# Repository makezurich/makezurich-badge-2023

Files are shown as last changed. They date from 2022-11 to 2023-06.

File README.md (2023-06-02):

## #MakeZurich 2023 Badge

## Pinout
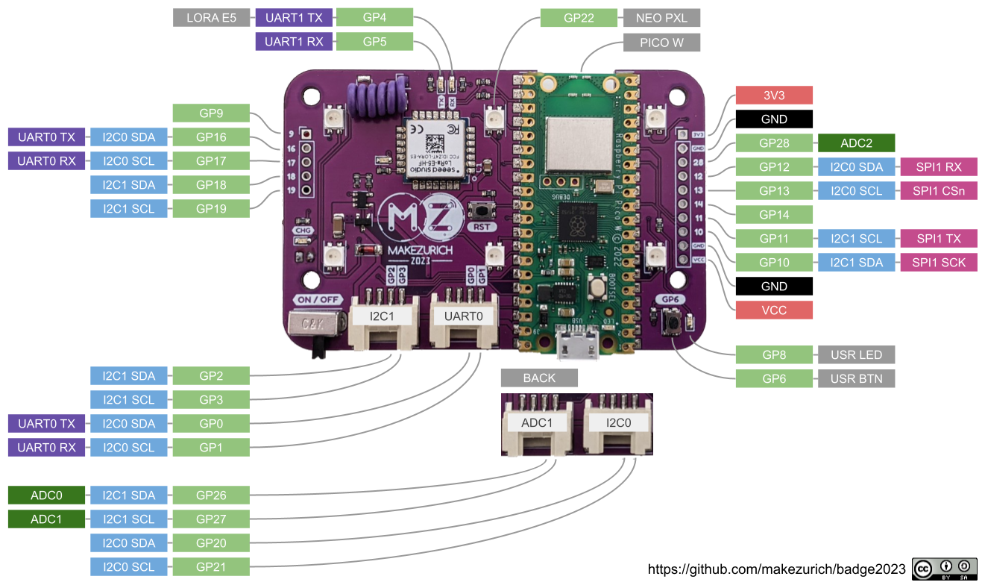
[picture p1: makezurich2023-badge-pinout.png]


## PSU
* Adafruit Feather LiPo circuit

## IO
* LoRa E5
* Shitty Addon
* Cover connectors 
* Grove connectors

## Resources

### CircuitPython
https://github.com/makezurich/badge2023-circuitpython

https://github.com/todbot/circuitpython-tricks

https://www.circuitpython.org

### LoRa E5
https://wiki.seeedstudio.com/Grove_LoRa_E5_New_Version/

https://www.hackster.io/sidikalamini/grove-lora-e5-p2p-communication-using-circuitpython-f970e6

https://files.seeedstudio.com/products/317990687/res/LoRa-E5%20AT%20Command%20Specification_V1.0%20.pdf

#### Version
| title | date | author | id | mainfont | toc | toc-depth |
| --- | --- | --- | --- | --- | --- | --- |
|"Badge"|2022-09-20|Tillo|20220920183855|Cochin|true|2|
|"Badge"|2023-04-24|Fede|?|Cochin|true|2|
|"Badge"|2023-05-12|Fede|?|Cochin|true|2|

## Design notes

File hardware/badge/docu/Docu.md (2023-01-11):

---
title: "Badge"
date: 2022-09-20
author: Tillo
id: 20220920183855
mainfont: Cochin
toc: true
toc-depth: 2
---

## Badge 20.9.

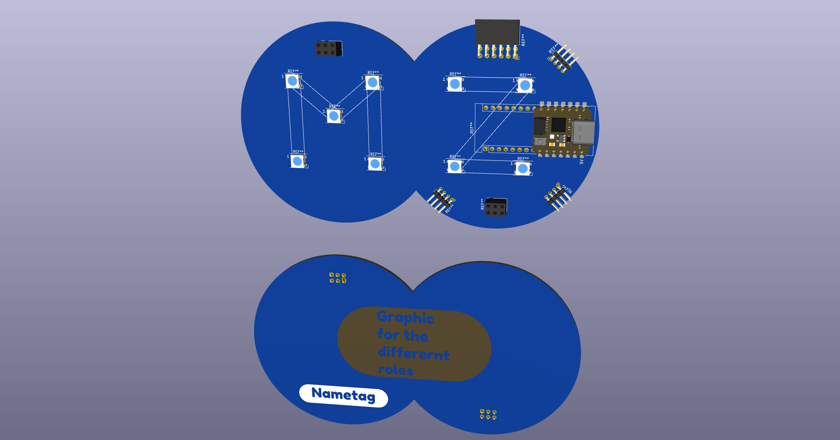
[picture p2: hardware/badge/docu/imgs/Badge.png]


## MCU
* Raspi Pico W

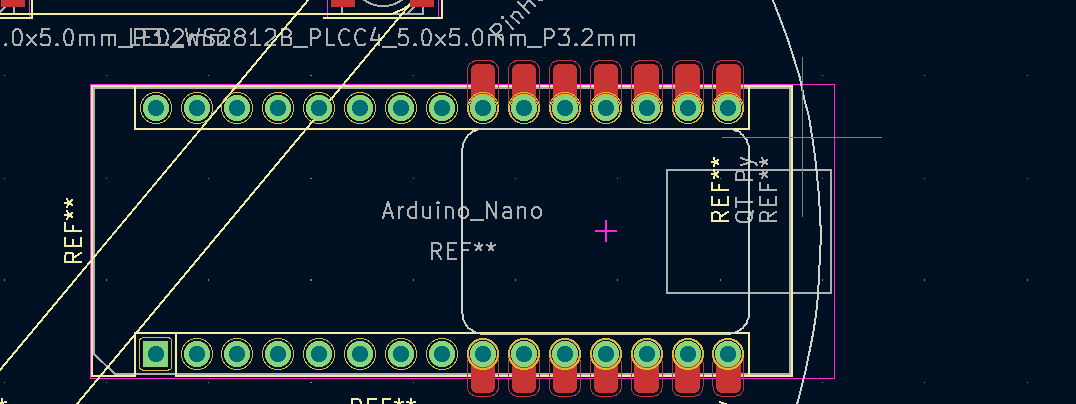
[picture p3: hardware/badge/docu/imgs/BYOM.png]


## Design 
* Sandwich
* LEDs shine trough the board
* Different graphics for the different roles 
* Touch button on the top 
* Resistors allow the badge to detect which role is plugged in

## PSU
* Same battery as last year
* Maybe ask the participants to bring their battery

## IO
* Shitty Addon
* Grove

## Prototyping area
* It was so nice let's do it twice

##  Open questions
* Batteries ?
* Shape ?
* Artwork ?
* Sponsors ? 
* µC

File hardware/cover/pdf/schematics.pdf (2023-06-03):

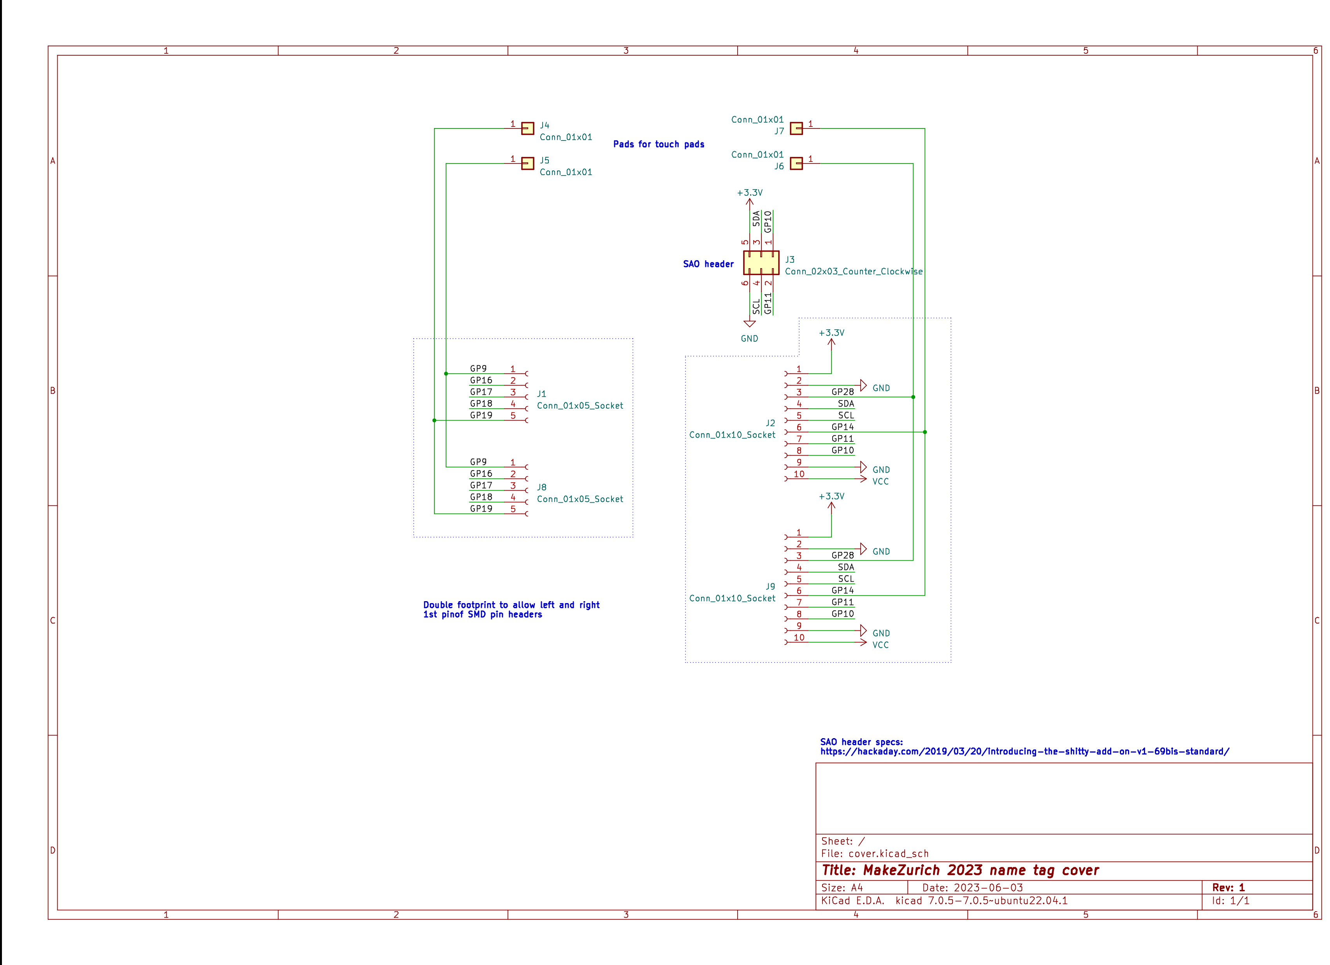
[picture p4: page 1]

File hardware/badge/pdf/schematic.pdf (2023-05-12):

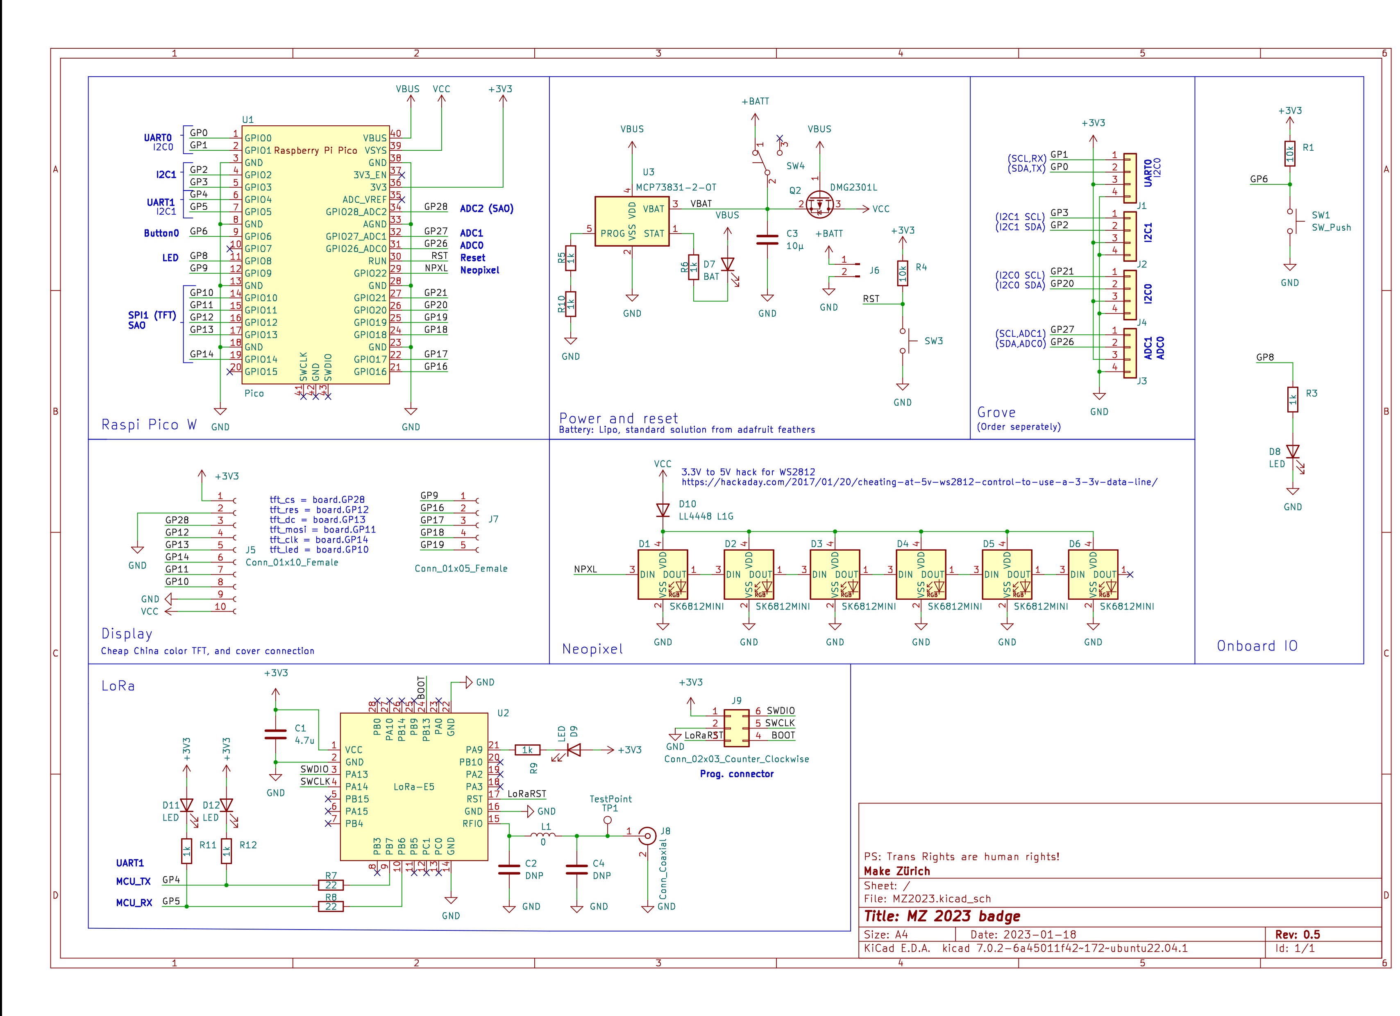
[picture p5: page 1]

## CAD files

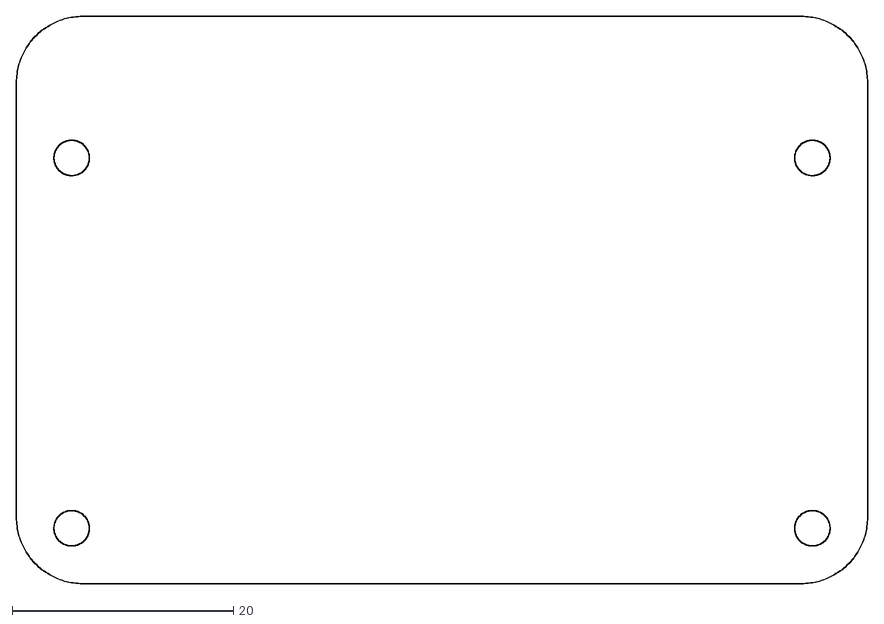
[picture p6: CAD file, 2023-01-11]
hardware/badge/docu/Badge_v20221102.dxf
77.0 x 51.3

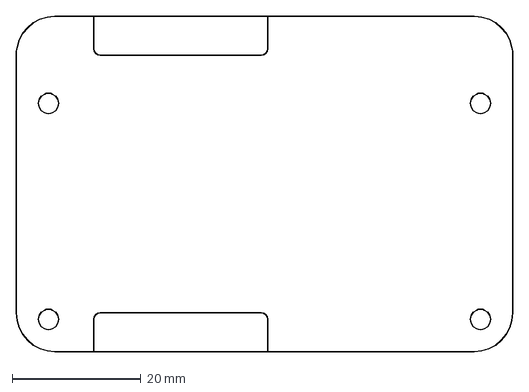
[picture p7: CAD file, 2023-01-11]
hardware/badge/docu/outlines_new.dxf
77.0 x 52.0 mm

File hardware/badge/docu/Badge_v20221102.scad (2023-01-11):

// CC BY-SA 4.0, MakeZurich.ch

$fn = 180;

// breadboard size
bbd_w = 81;
bbd_h = 51;

// AP9 box size
box_w = 77;
box_h = 77;
holes_w = 67;
holes_h = 33.5;
holes_r = 1.6;

// pico size
mcu_w = 21;
mcu_h = 51.3;
mcu_z = 3.9;

// badge size
// like breadboard
// but still fits in box
bdg_w = min(box_w, bbd_w);
bdg_h = max(min(box_h, bbd_h), mcu_h);

module base() {
  hull() {
    translate([6, 6]) {
      translate([0, 0]) {
        cylinder(1, 6, 6);
      }
      translate([bdg_w - 2 * 6, 0]) {
        cylinder(1, 6, 6);
      }
      translate([bdg_w - 2 * 6, bdg_h - 2 * 6]) {
        cylinder(1, 6, 6);
      }
      translate([0, bdg_h - 2 * 6]) {
        cylinder(1, 6, 6);
      }
    }
  }
}

module base_w_holes(){
    difference(){
        base();
        #translate([5,5,0]){
            cylinder(2,r=holes_r,center=true);
        };
        #translate([5+holes_w,5,0]){
            cylinder(2,r=holes_r,center=true);
        };        
        #translate([5,5+holes_h,0]){
            cylinder(2,r=holes_r,center=true);
        };        
        #translate([5+holes_w,5+holes_h,0]){
            cylinder(2,r=holes_r,center=true);
        };
    }
}

// board
//base_w_holes();

// translate([box_w - mcu_w - 10, 0, 1]) {
//  cube([mcu_w, mcu_h, mcu_z]);
//}

// cover
//translate([0, 0, 10]) base();

// dxf or svg export
//

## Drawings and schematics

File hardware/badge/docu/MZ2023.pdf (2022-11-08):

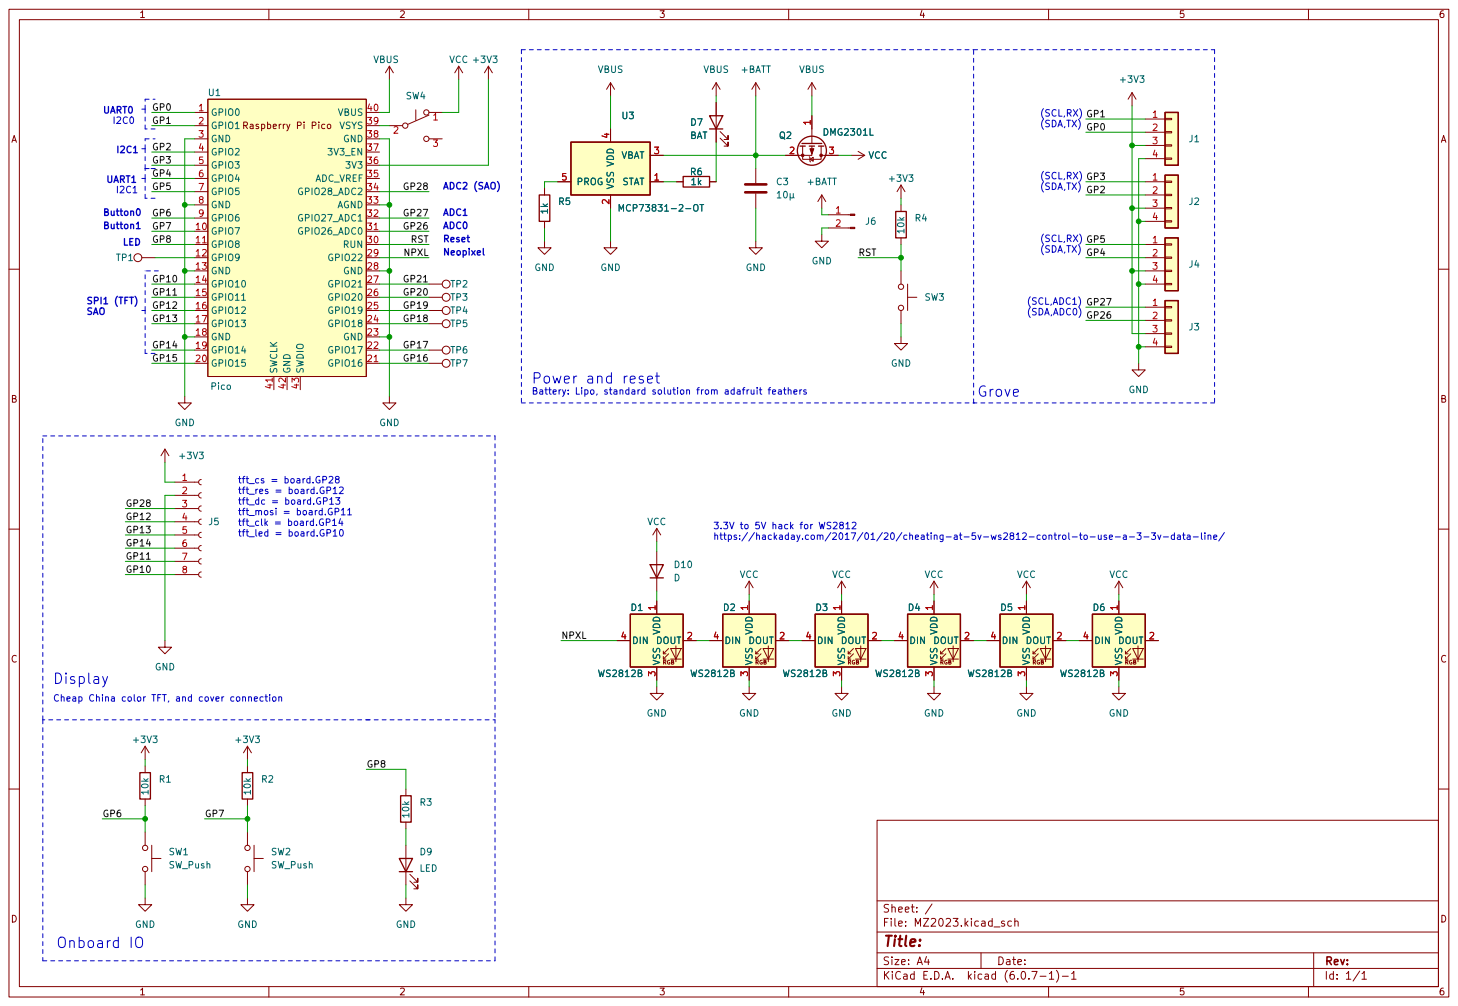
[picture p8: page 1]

I2C1 UART1 Cheap China color TFT, and cover connection

4 PROG 5 U3MCP73831-2-OT VBUS VBUS +BATT VBUS GP7 GP11 GP13 GP8 GP14 GP6

https://hackaday.com/2017/01/20/cheating-at-5v-ws2812-control-to-use-a-3-3v-data-line/ ADC1 ADC2 (SAO)

Power and reset
Battery: Lipo, standard solution from adafruit feathers

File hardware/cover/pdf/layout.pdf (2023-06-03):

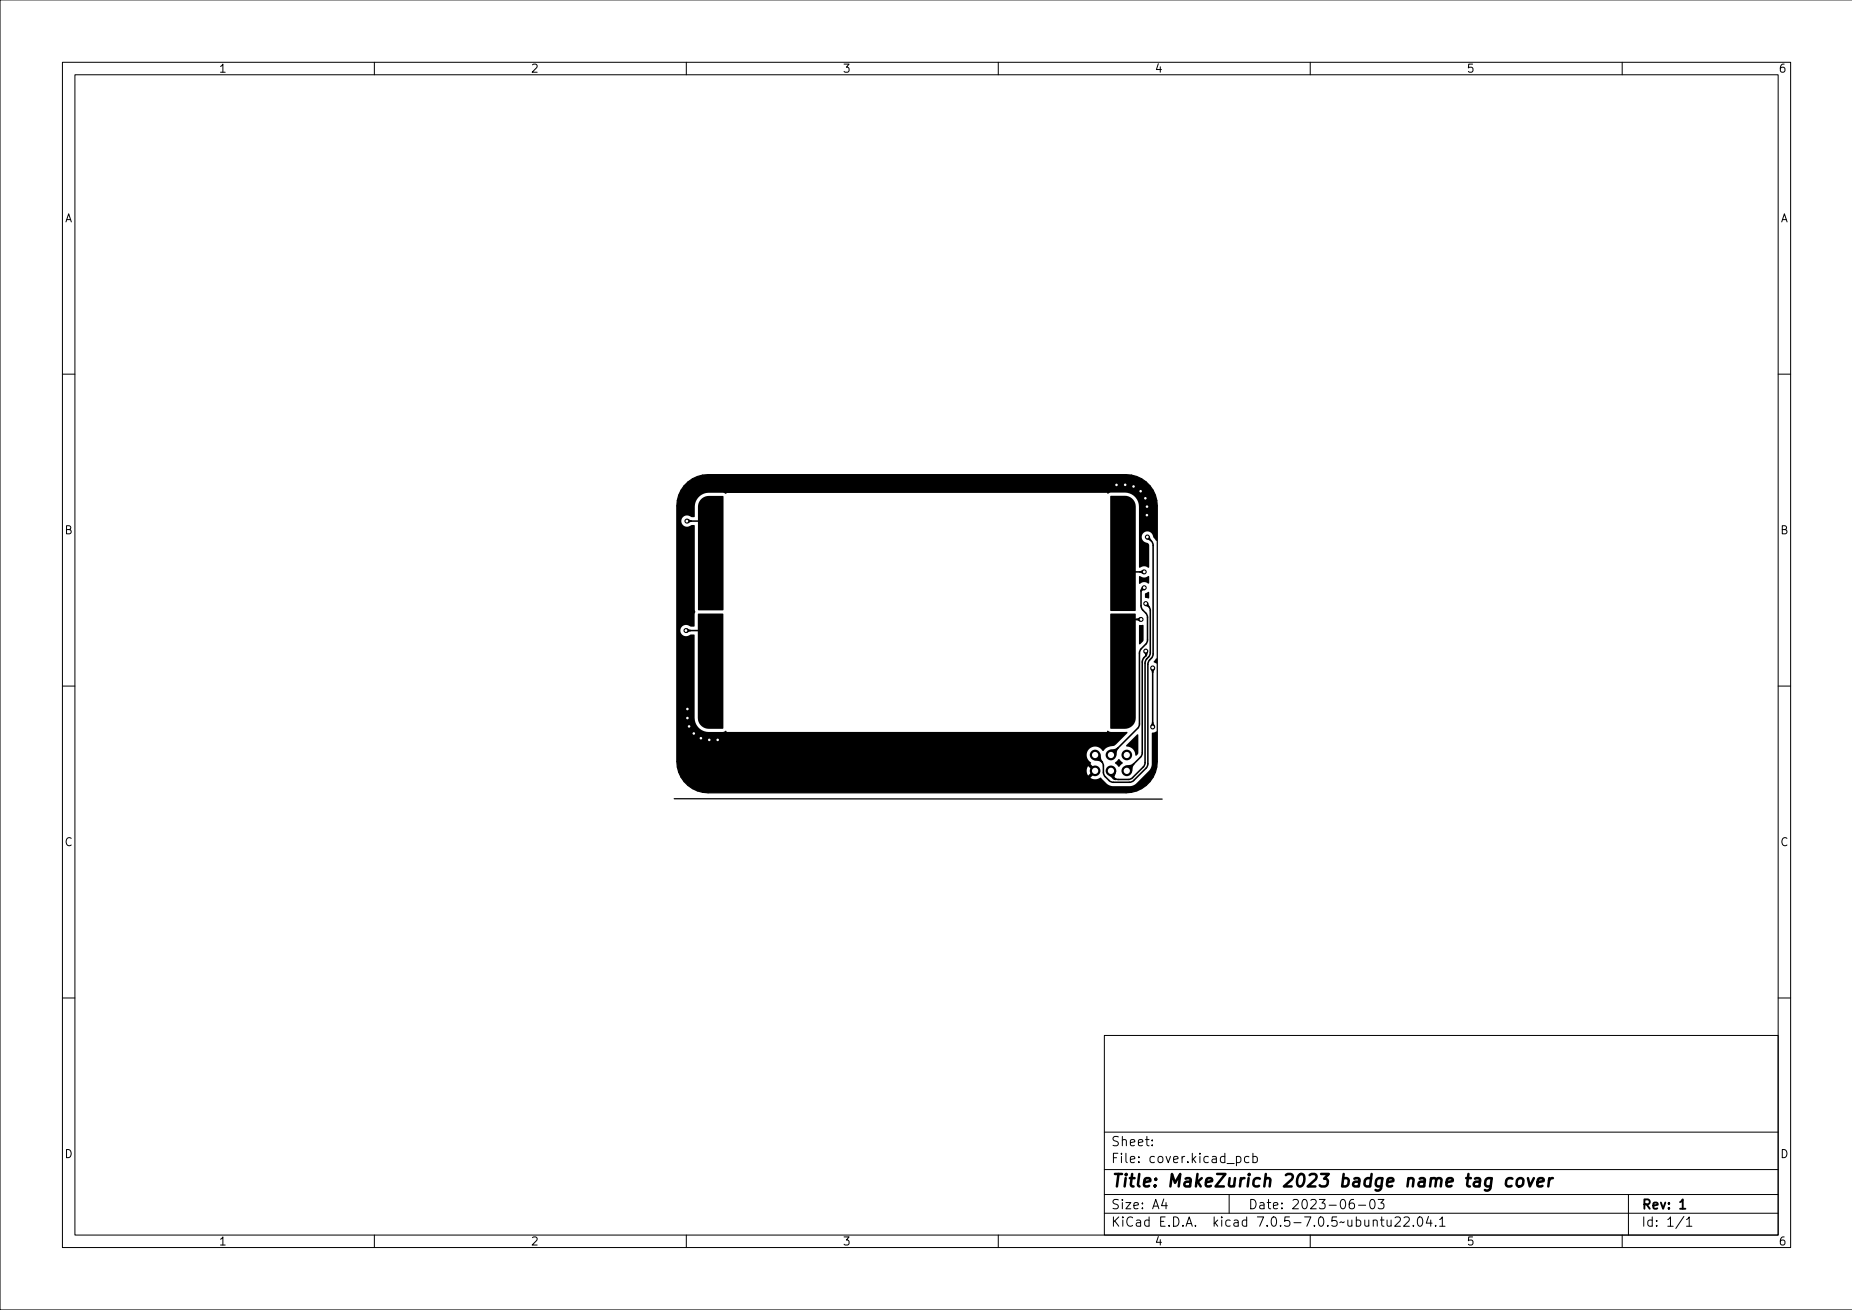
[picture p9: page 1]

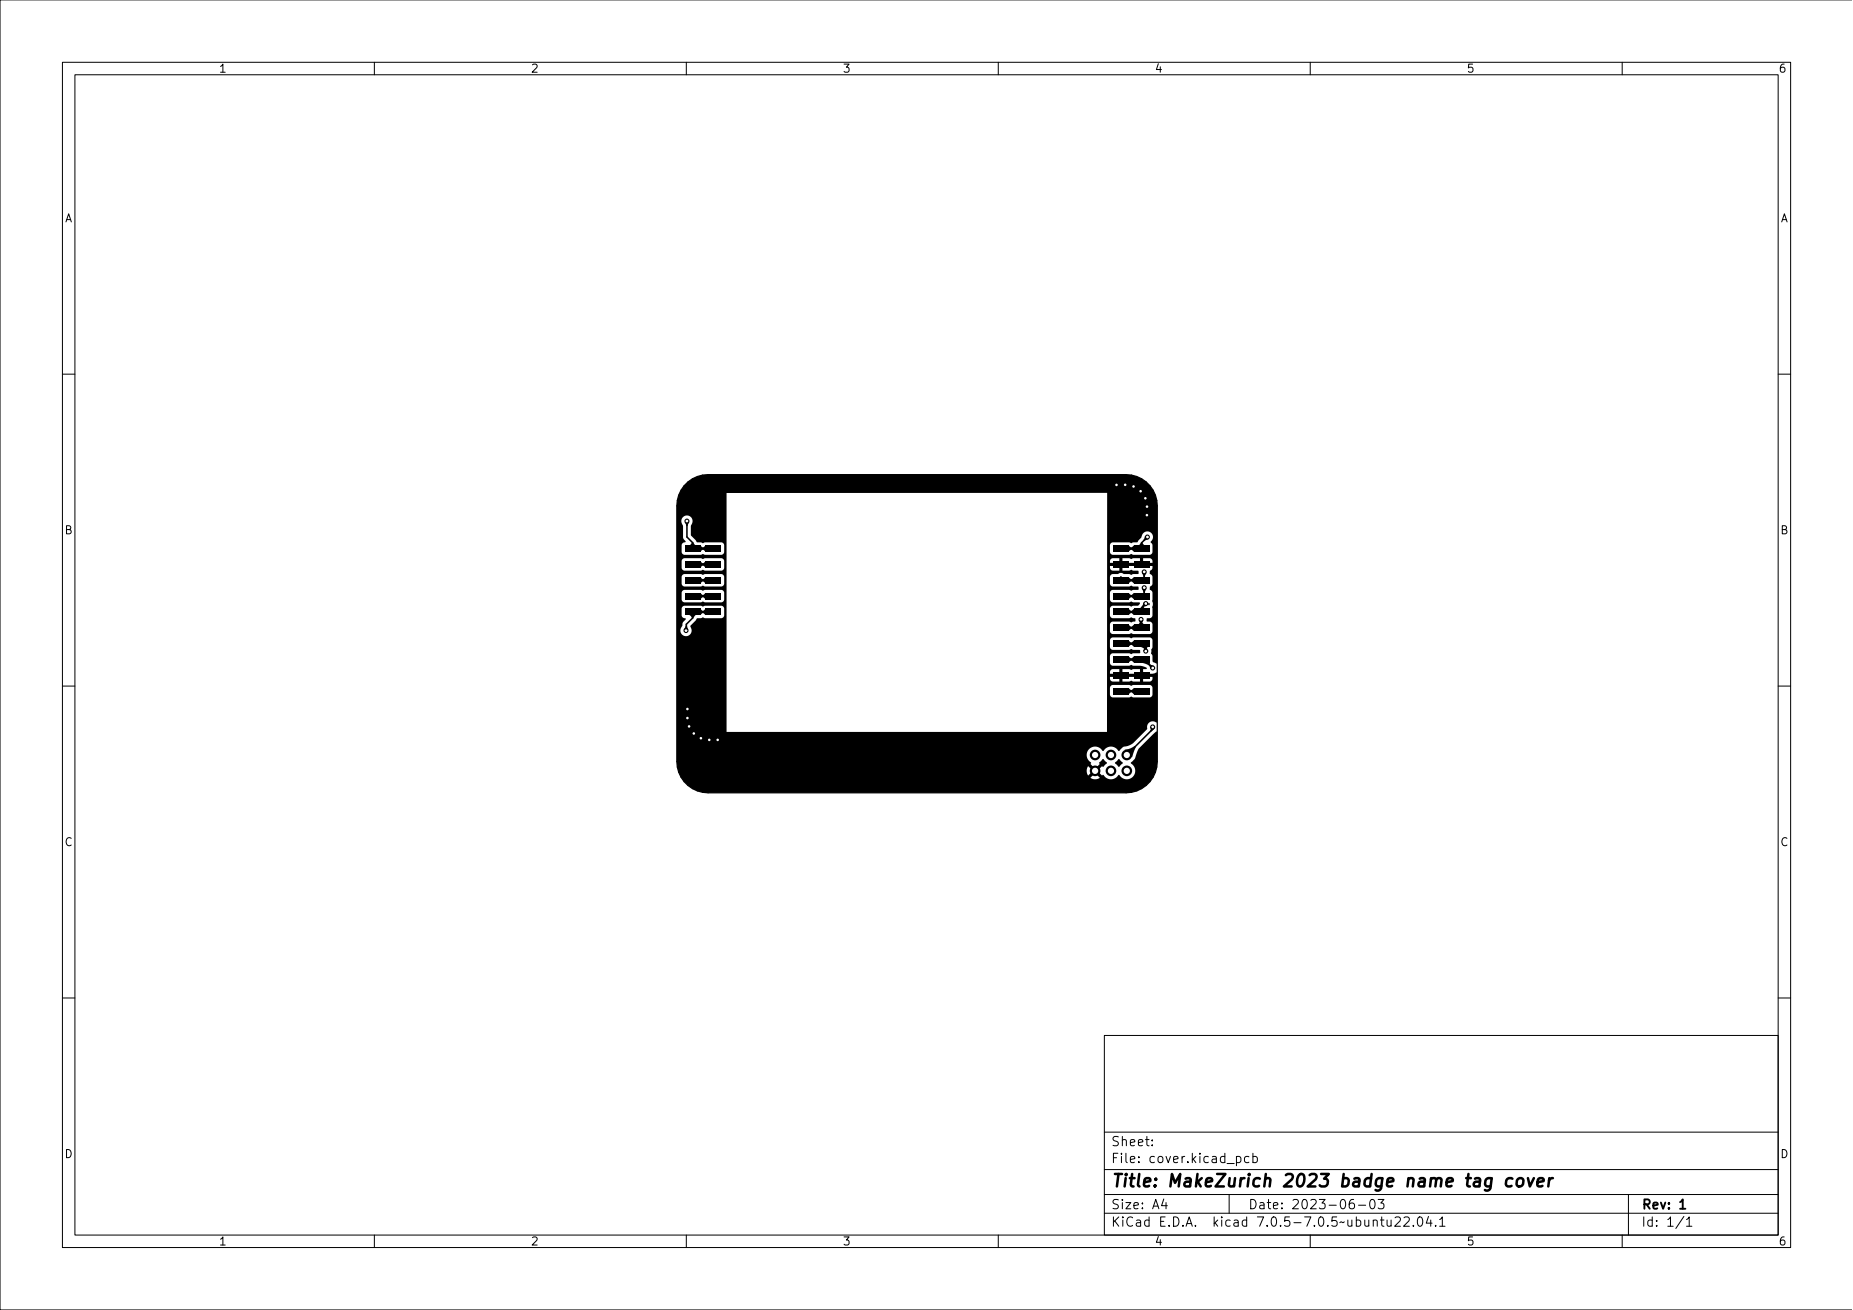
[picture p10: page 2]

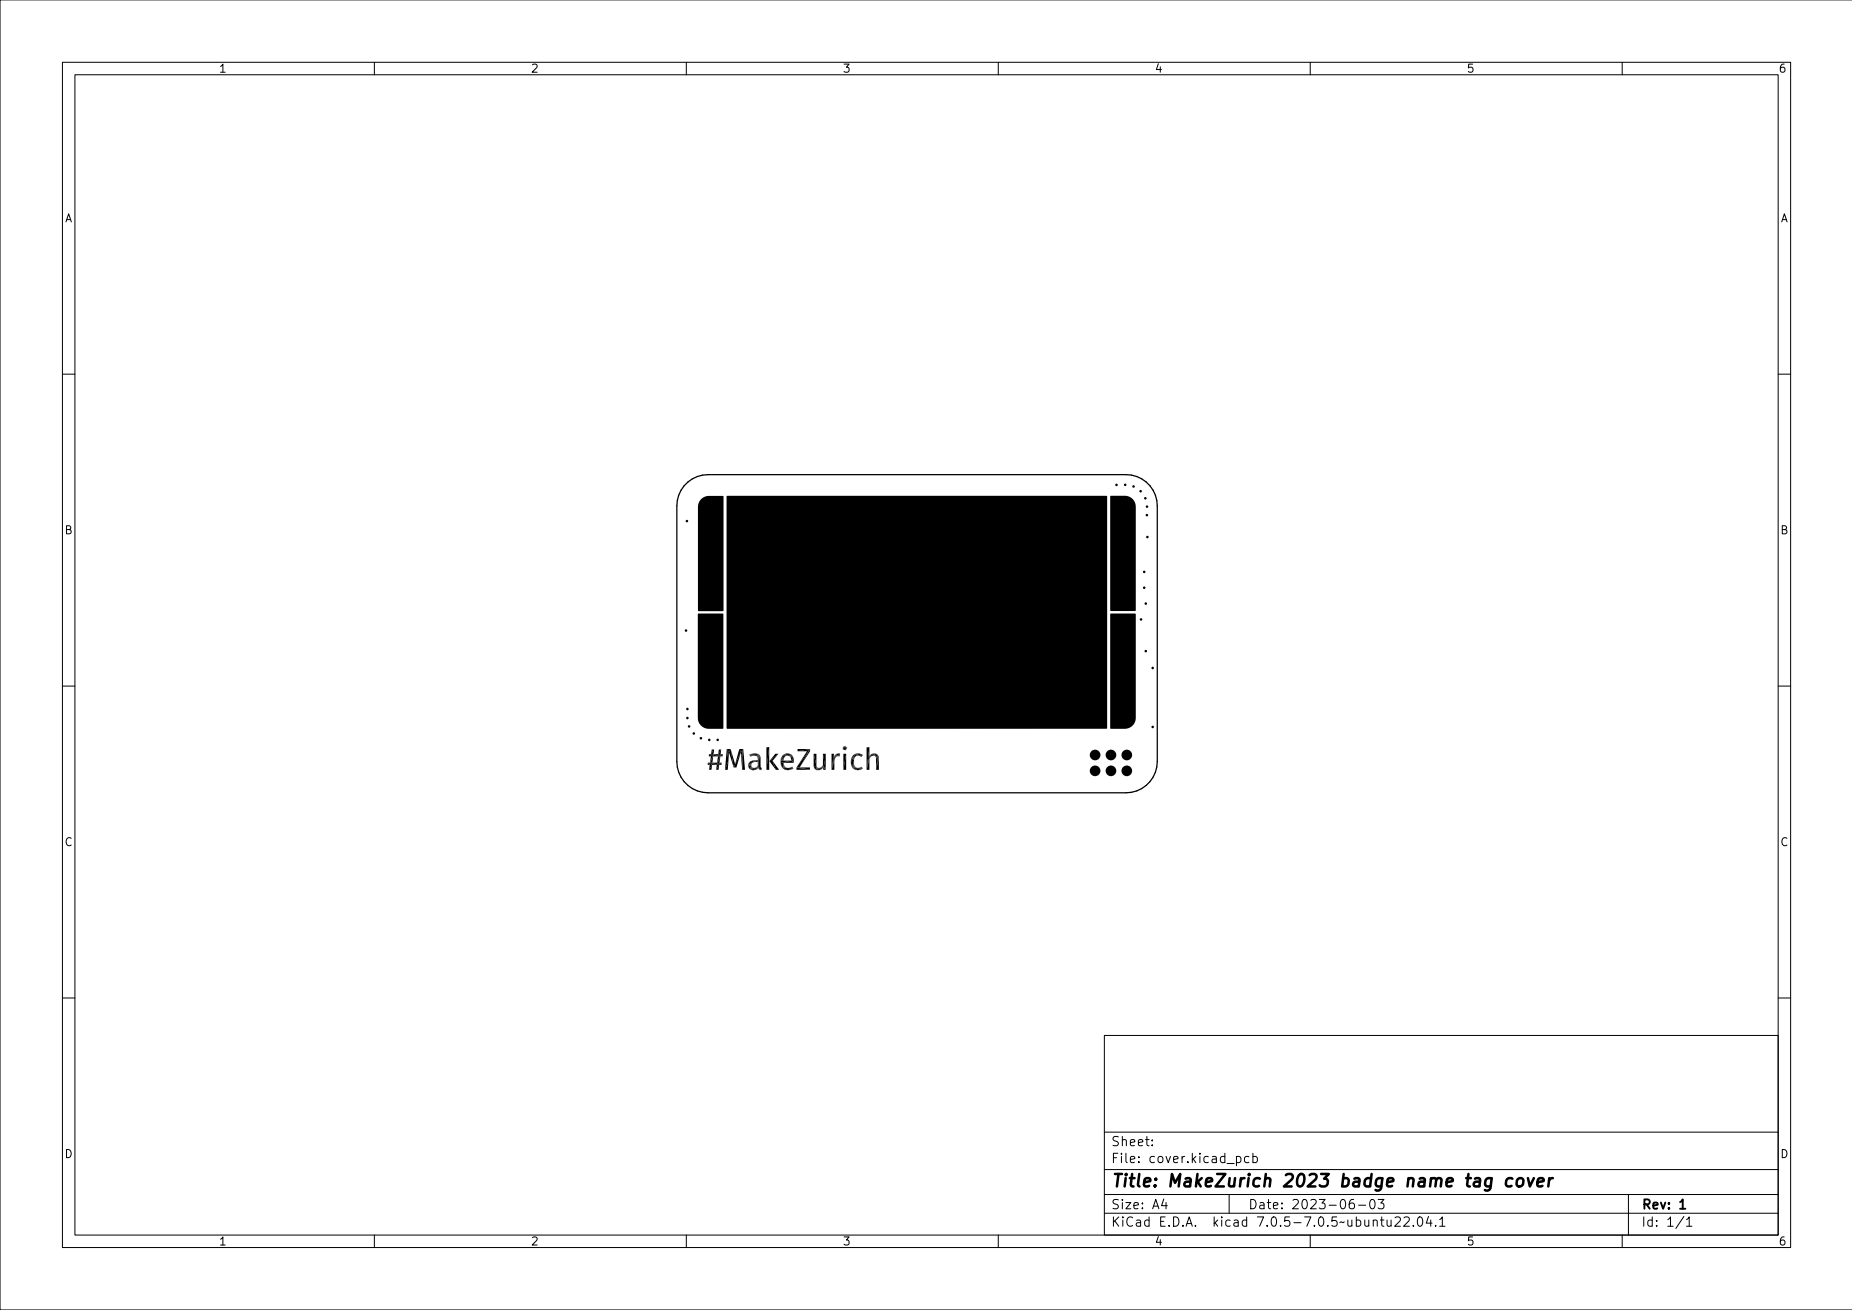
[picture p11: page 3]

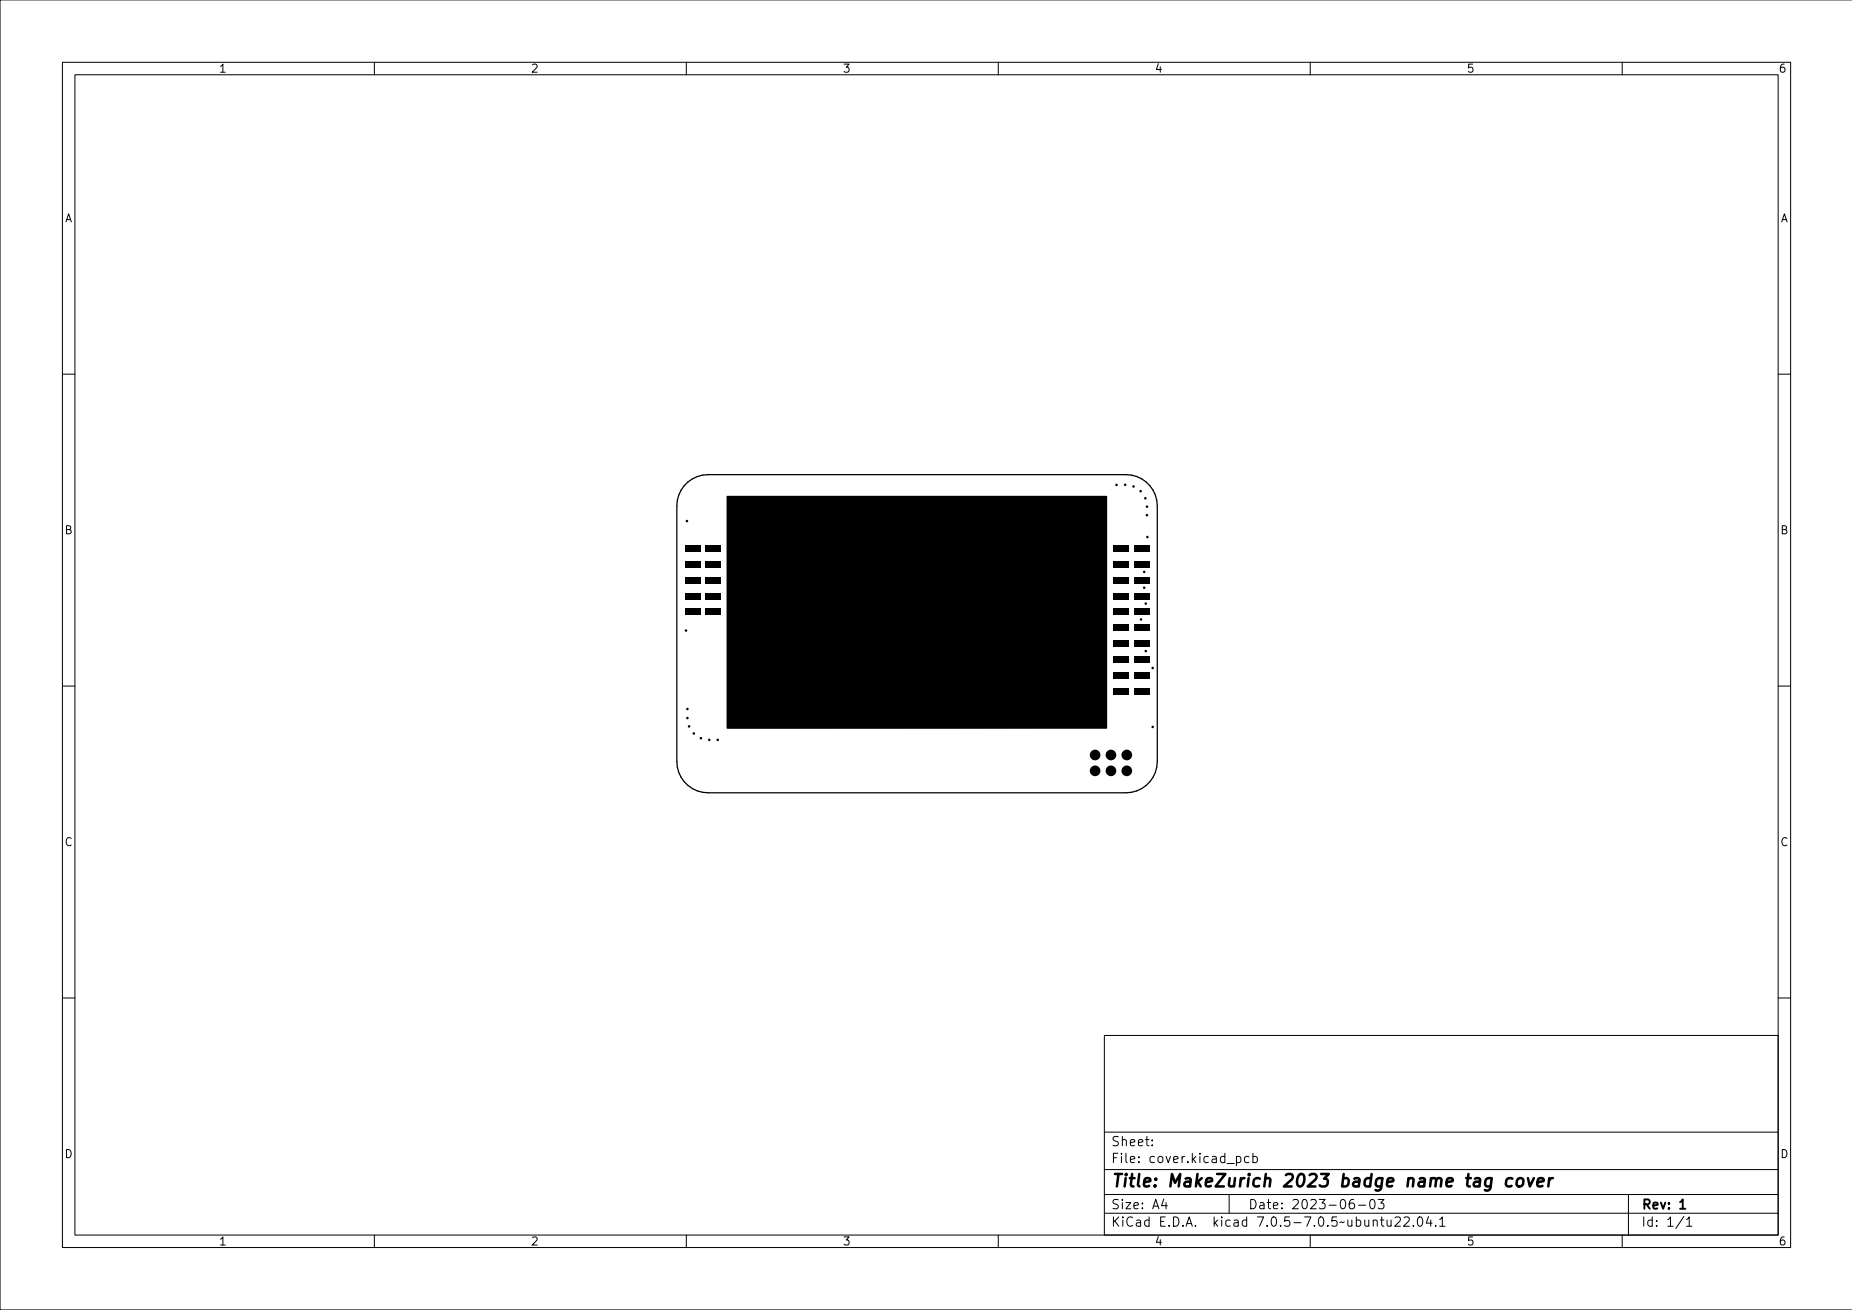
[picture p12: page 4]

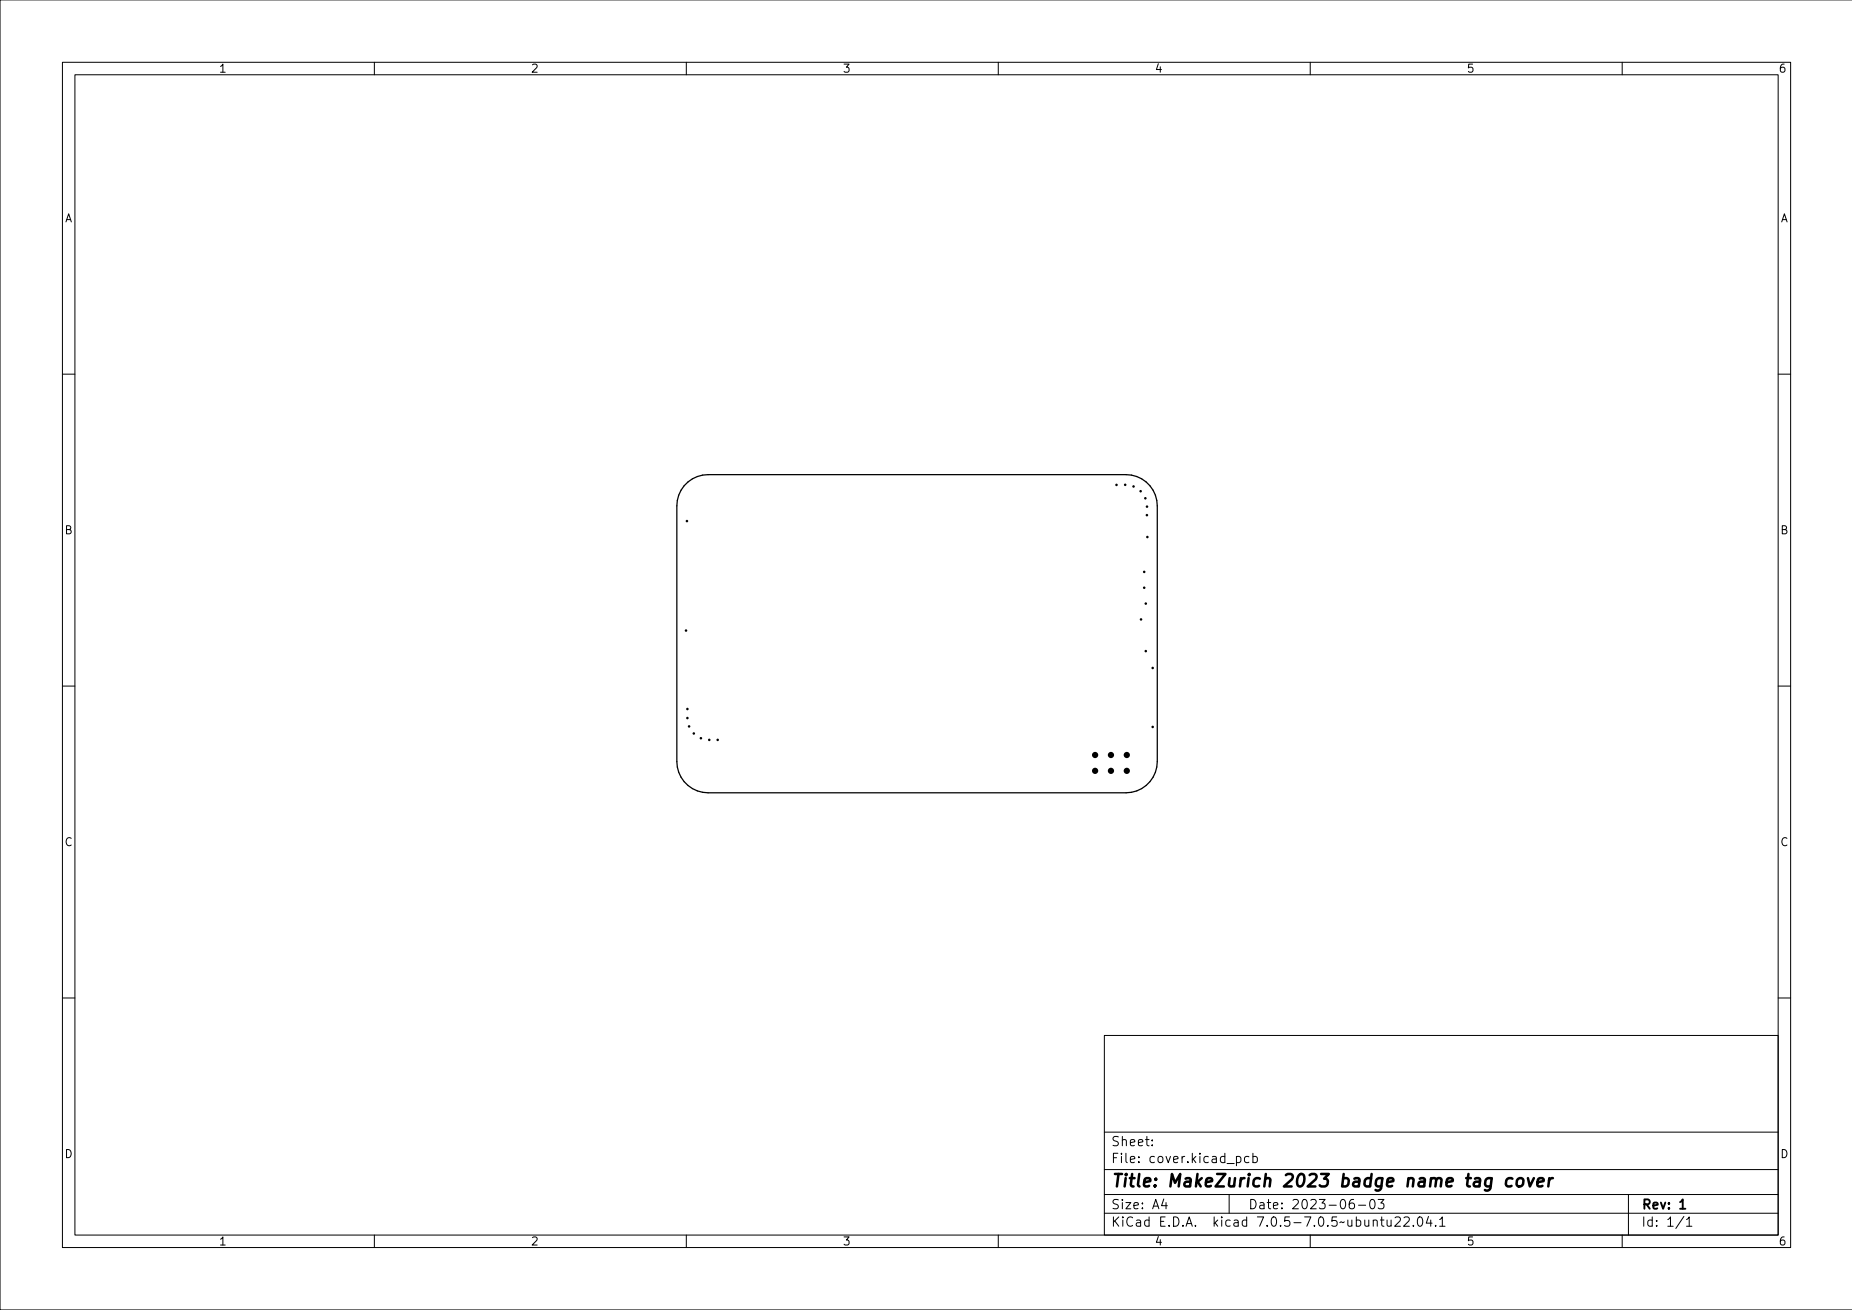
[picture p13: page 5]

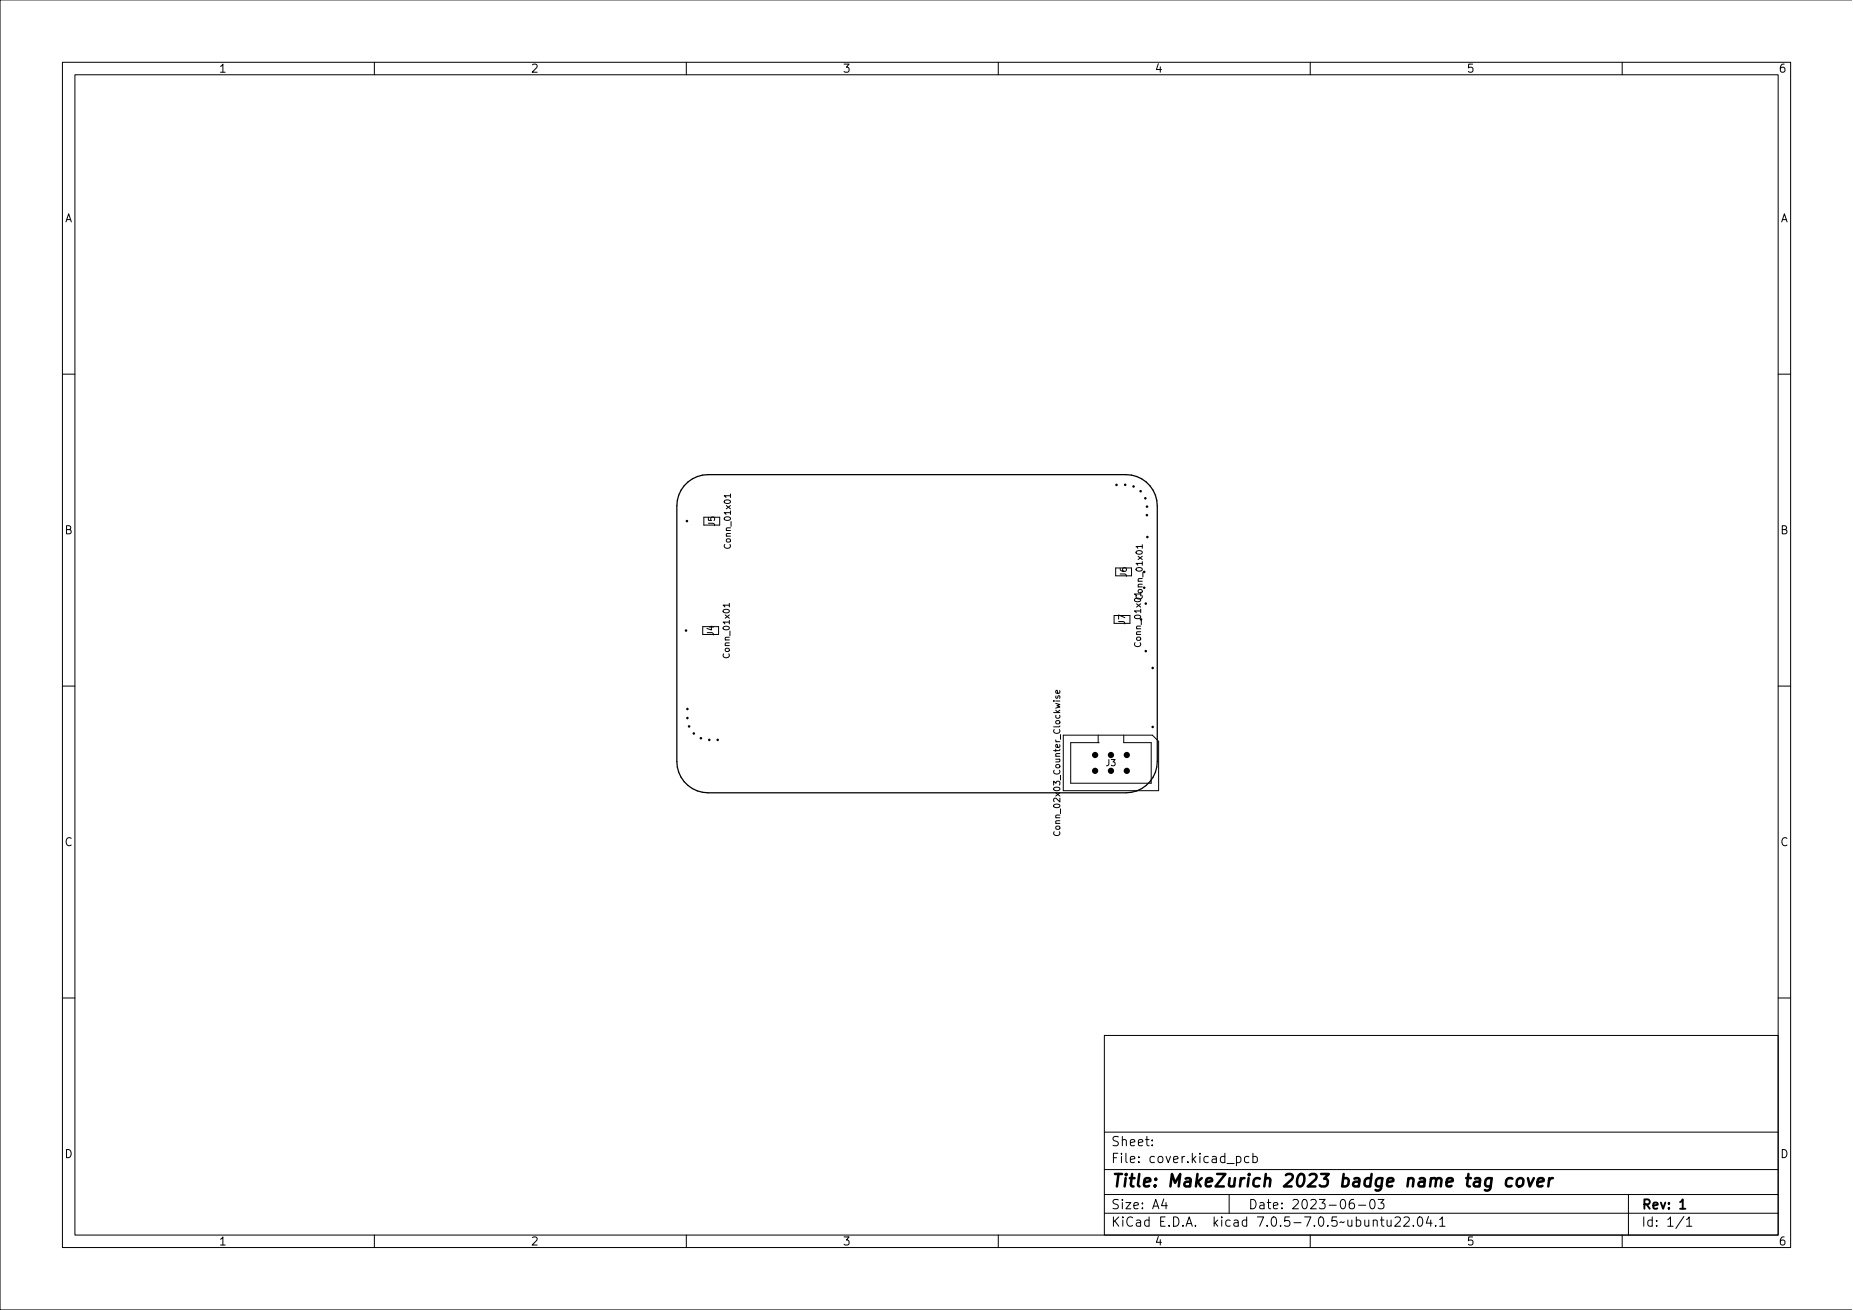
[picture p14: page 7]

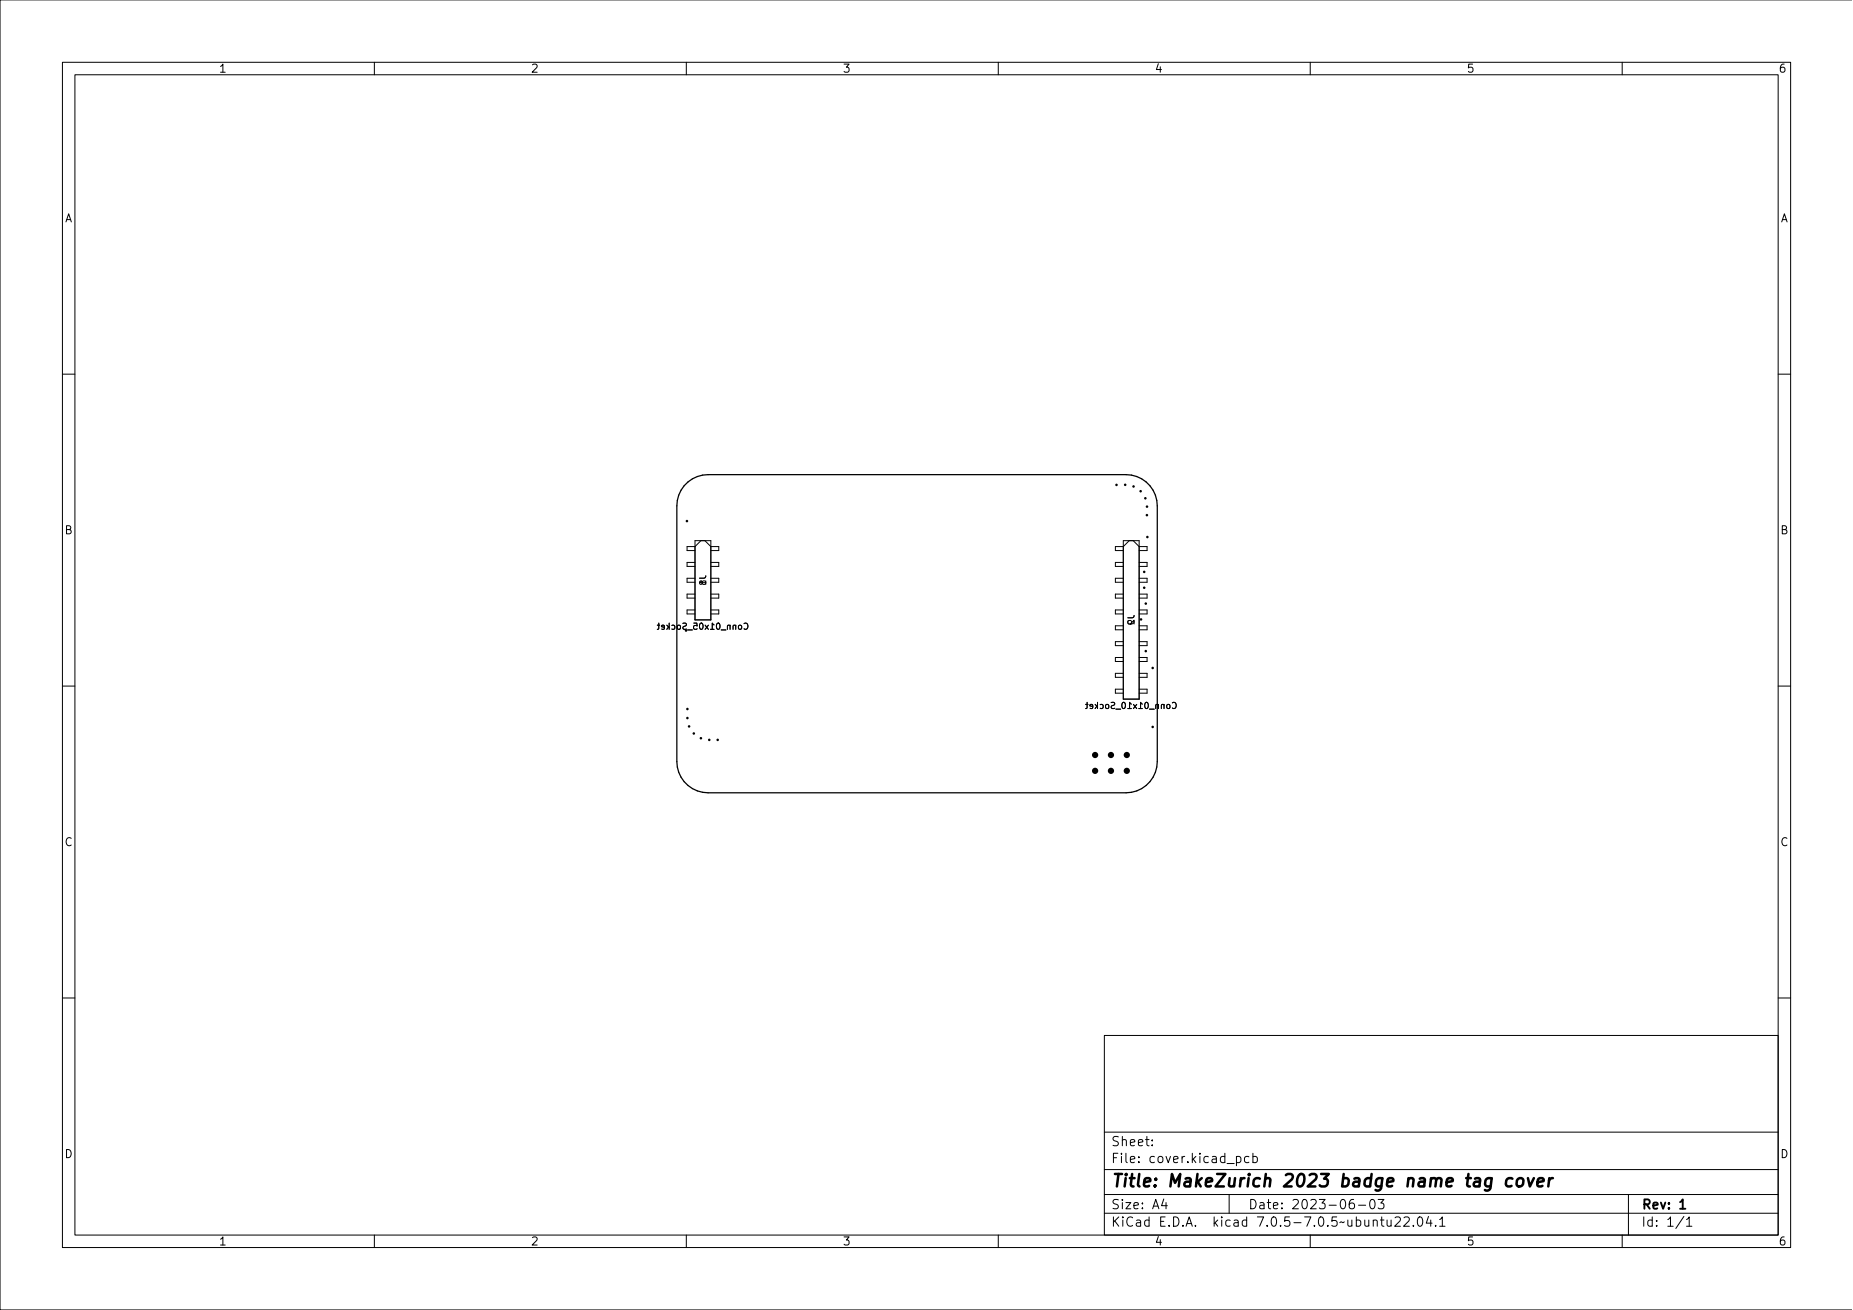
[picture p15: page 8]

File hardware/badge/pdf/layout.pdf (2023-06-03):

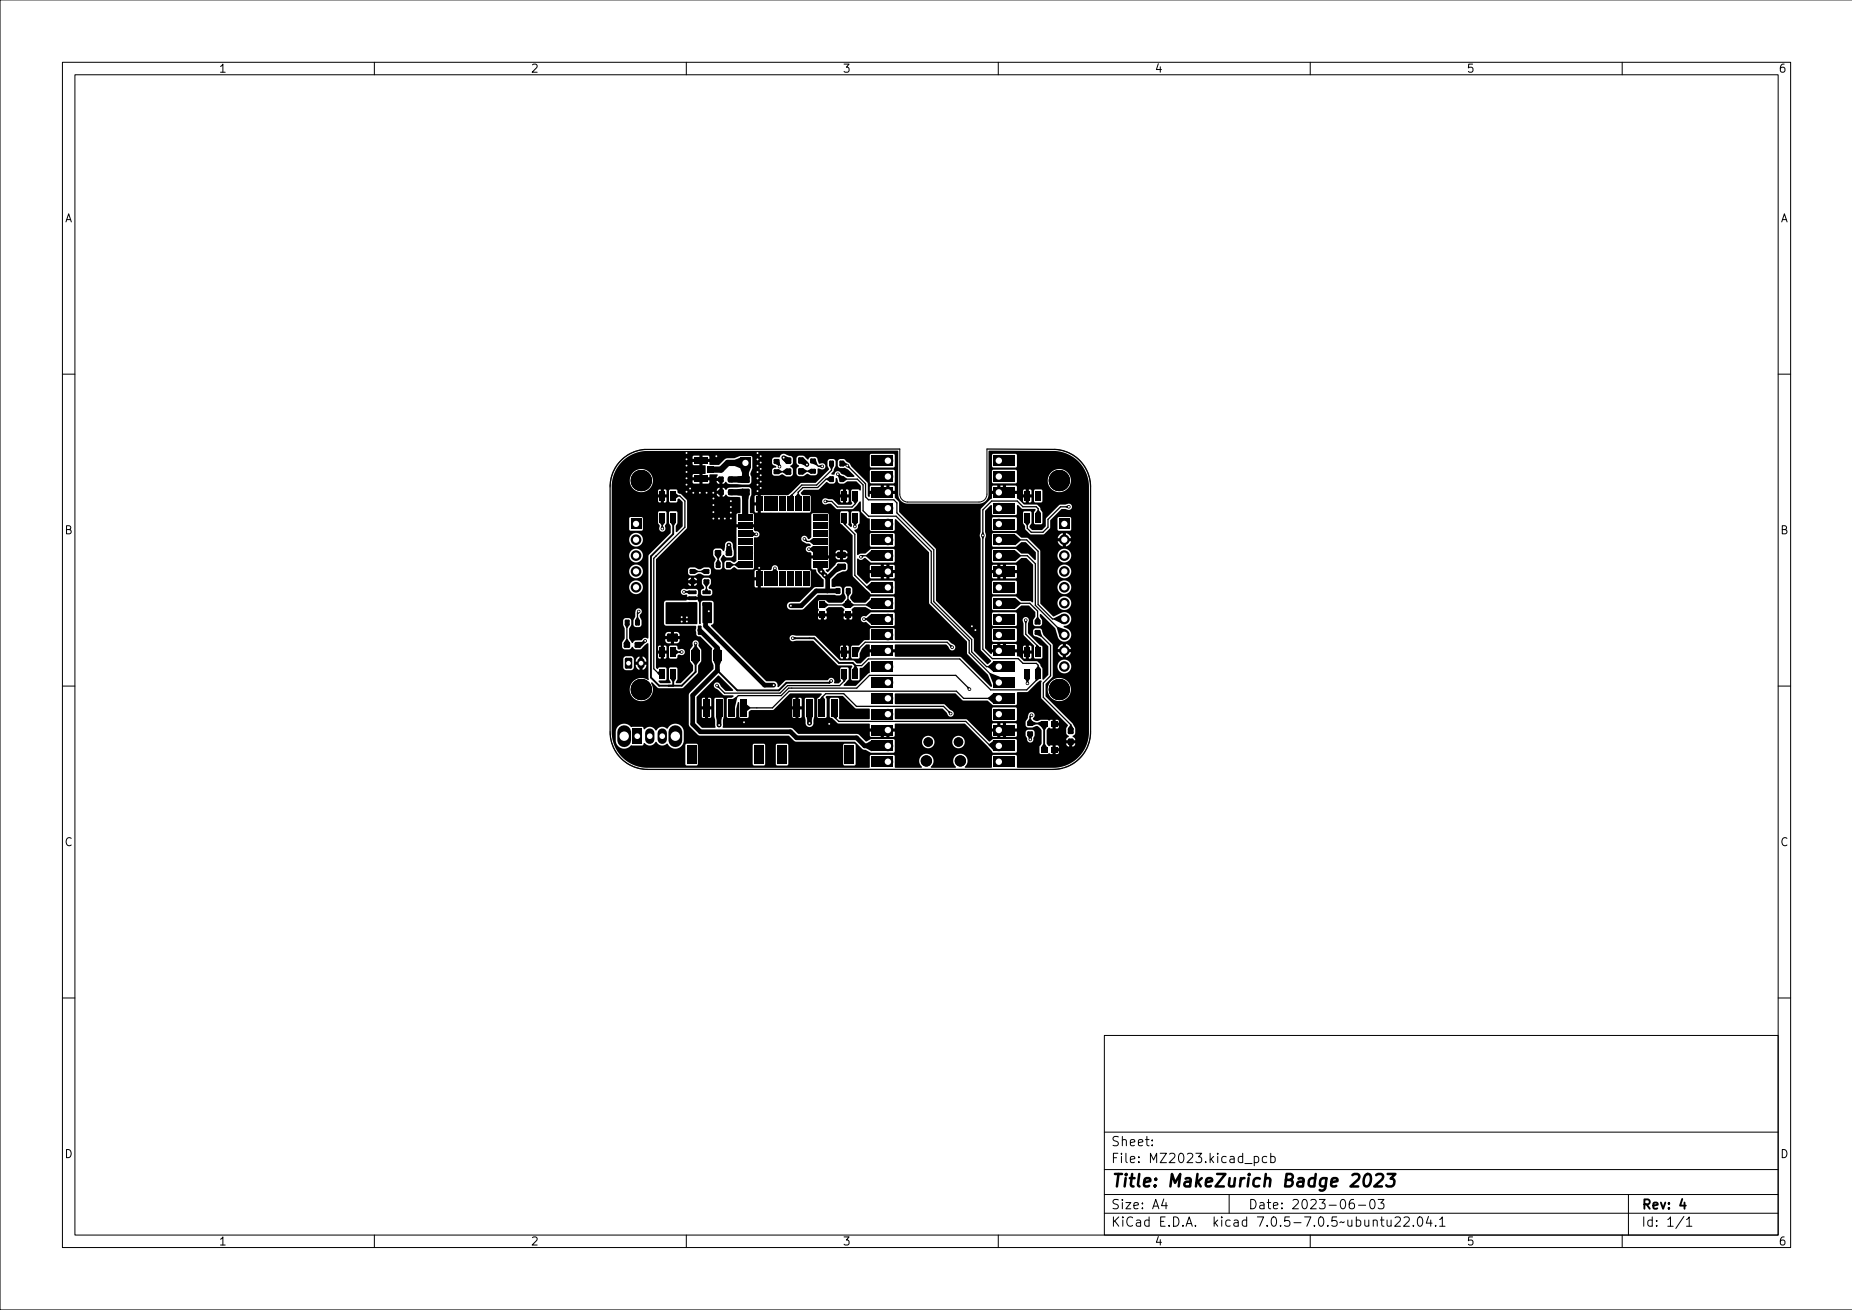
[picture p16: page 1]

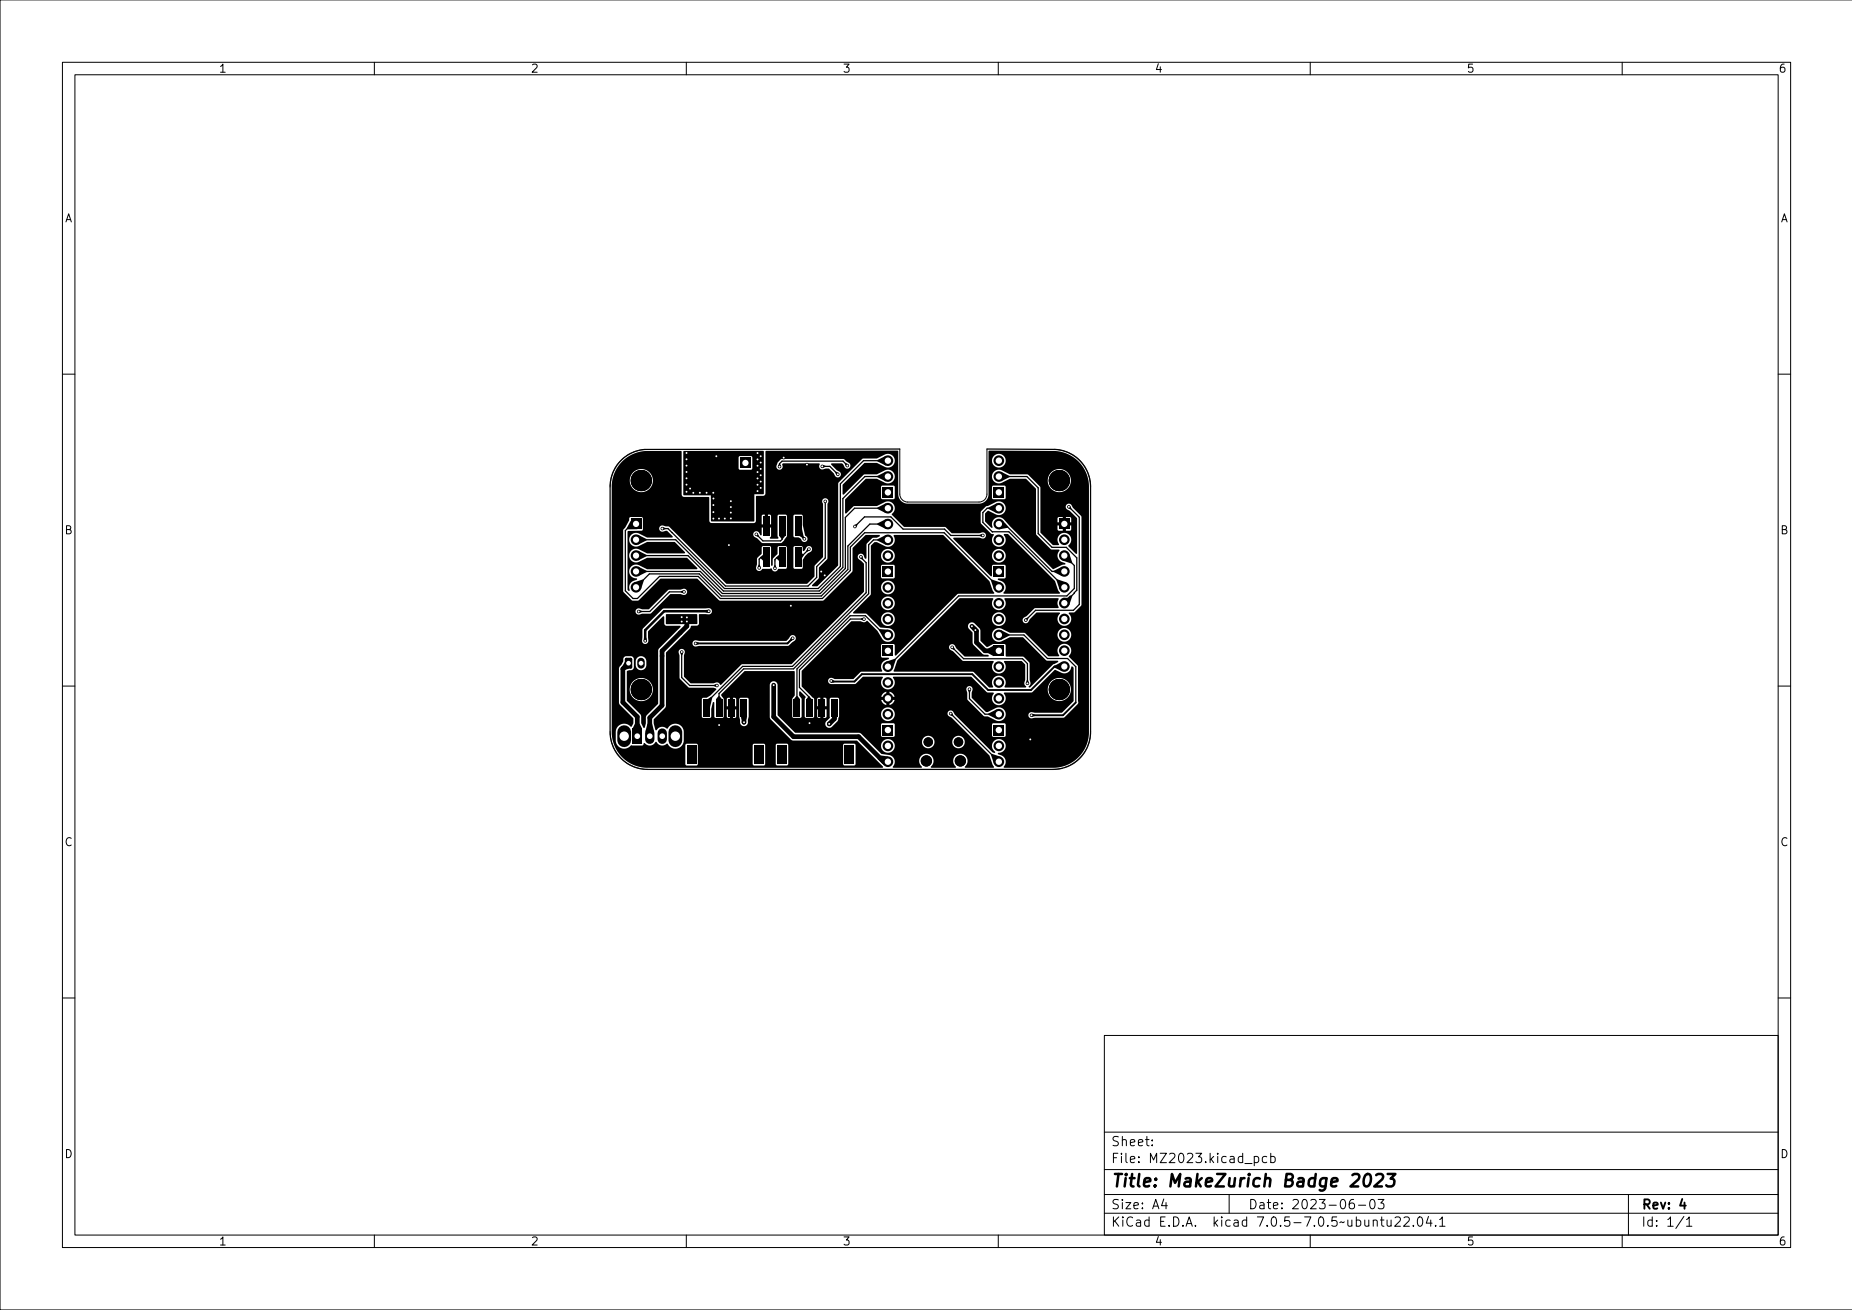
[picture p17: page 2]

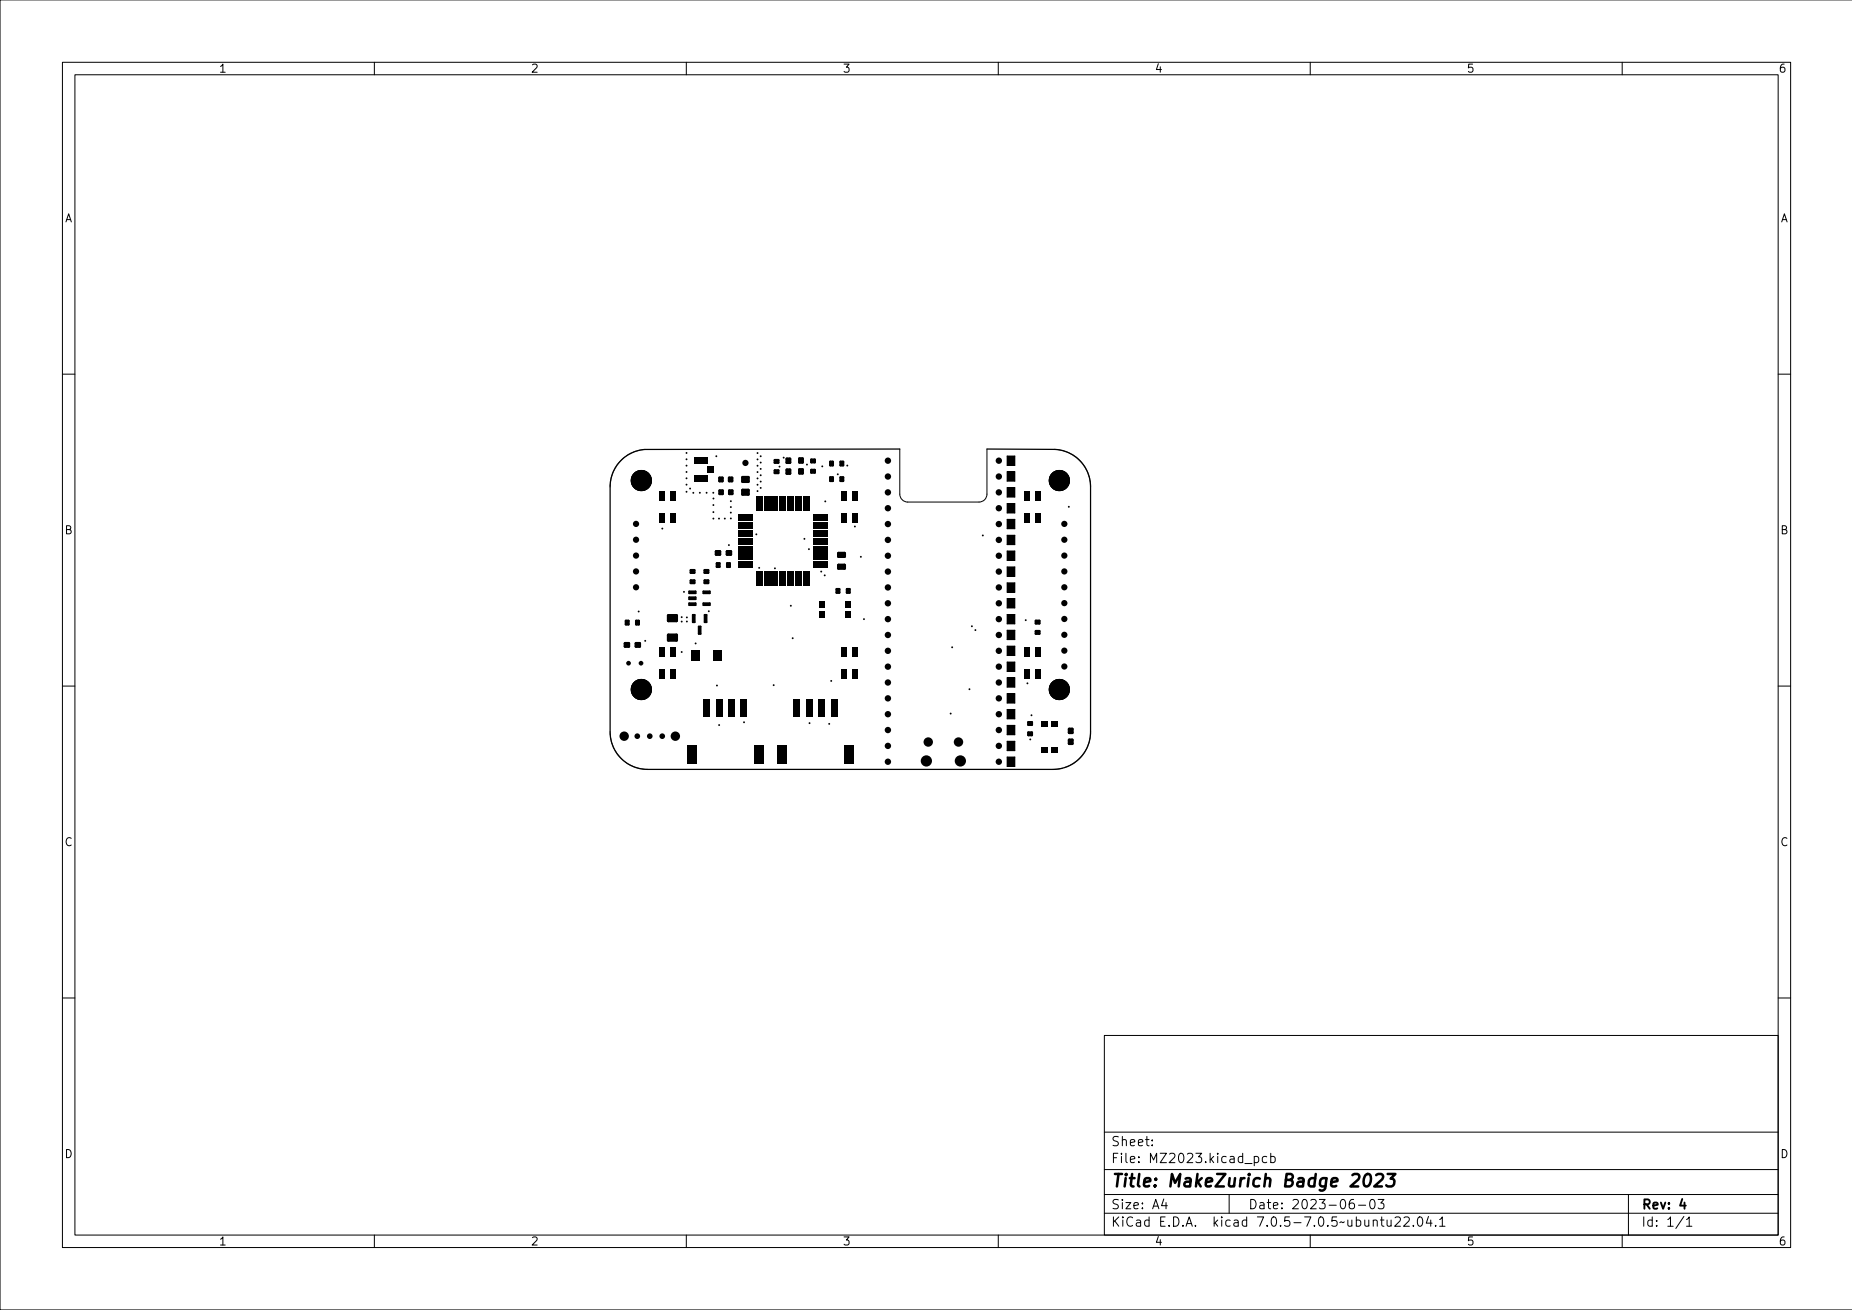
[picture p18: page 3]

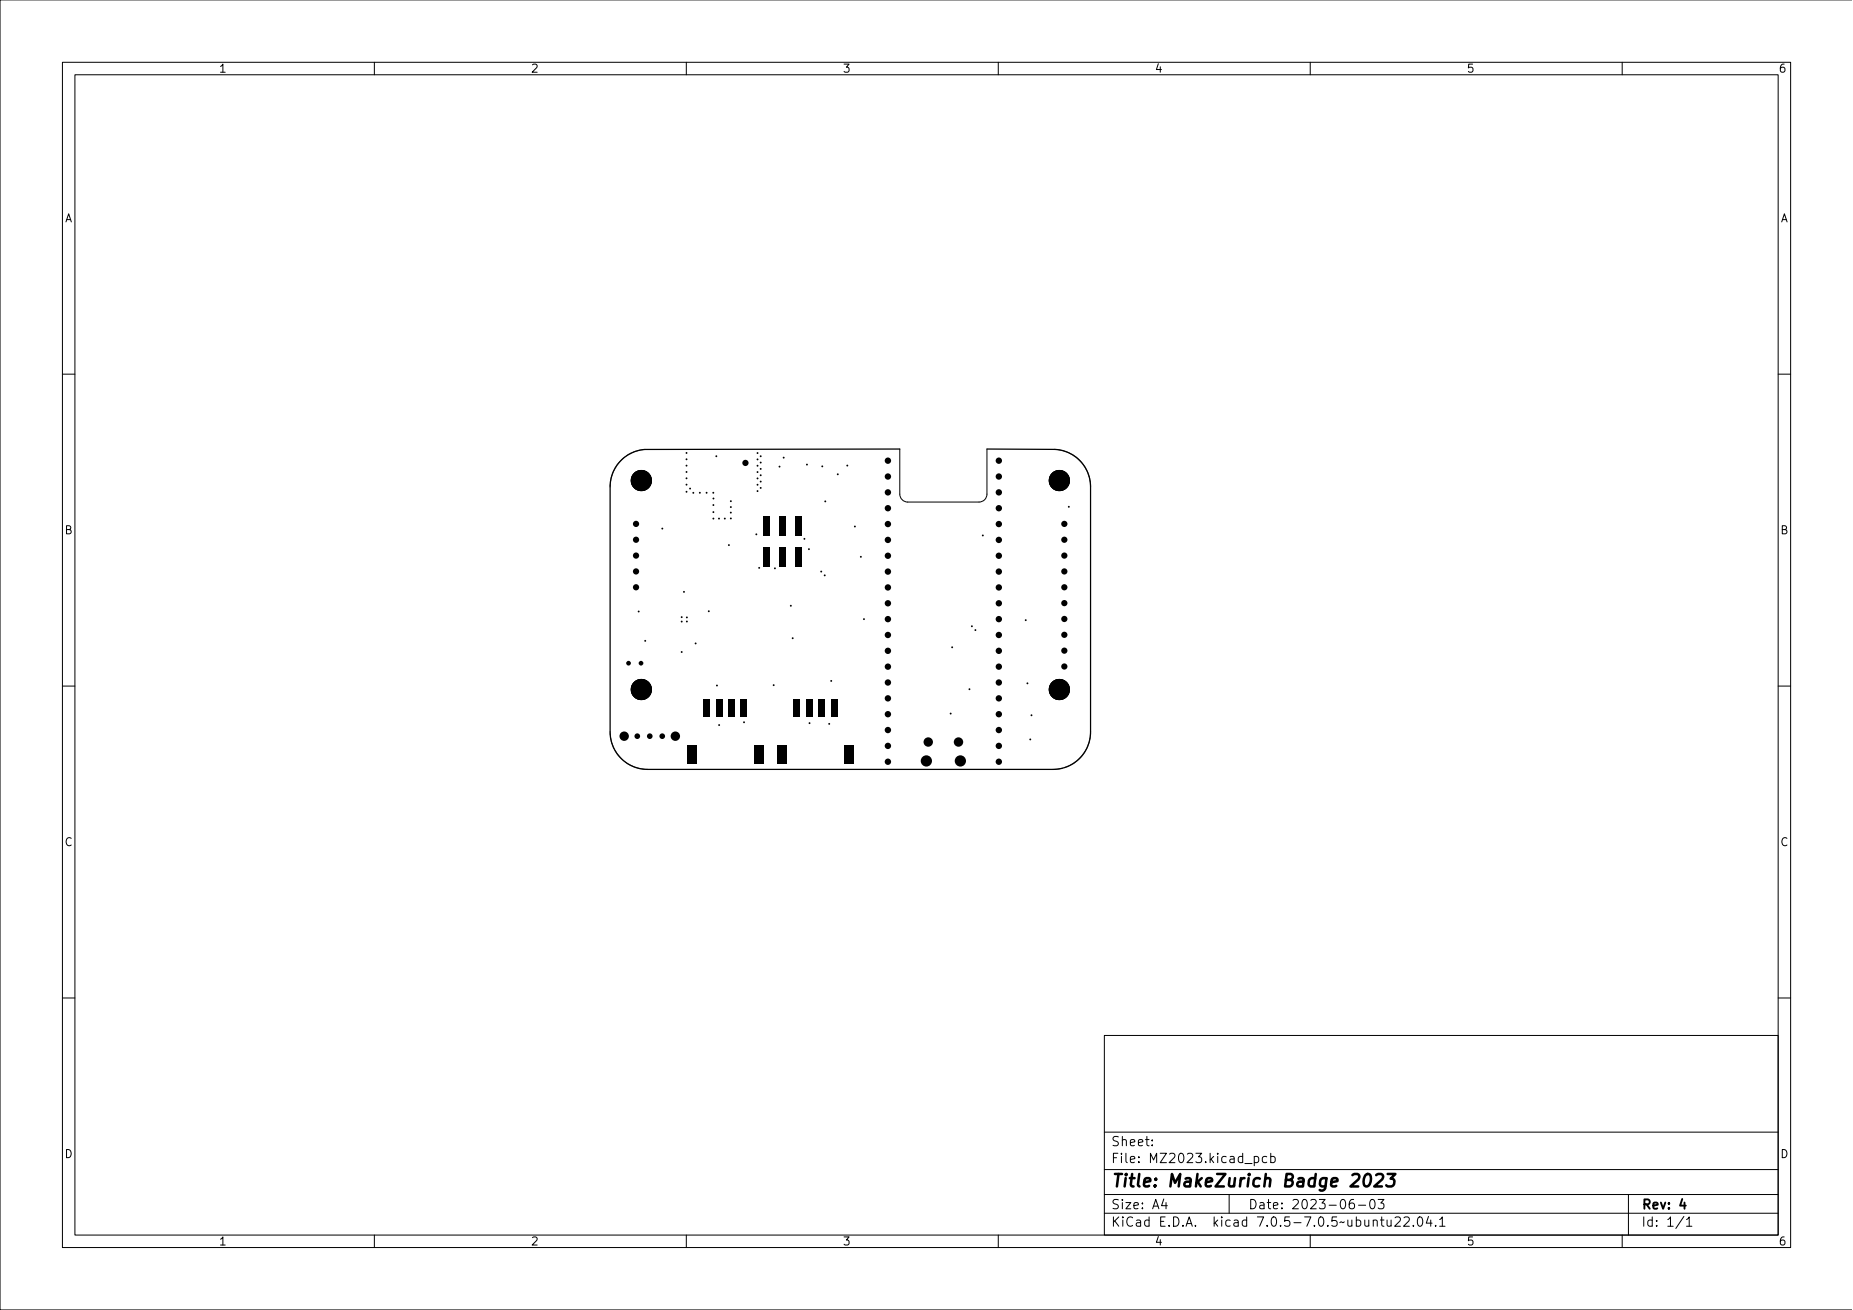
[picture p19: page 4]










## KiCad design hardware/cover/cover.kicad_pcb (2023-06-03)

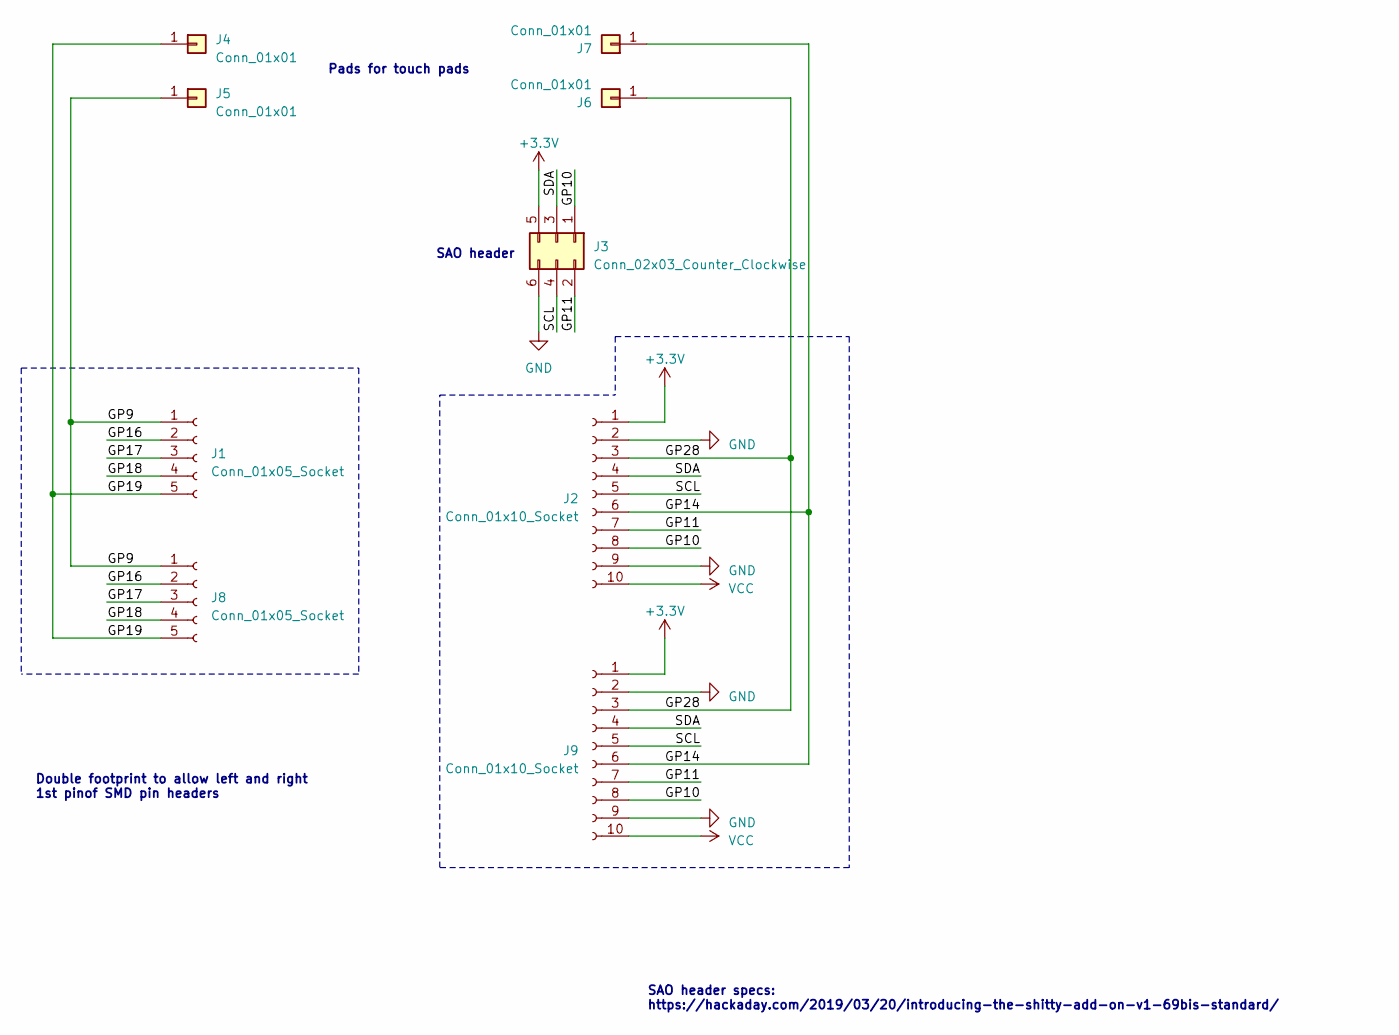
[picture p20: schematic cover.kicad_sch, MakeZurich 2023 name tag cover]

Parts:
J1: Conn_01x05_Socket; PinHeader_1x05_P2.54mm_Vertical_SMD_Pin1Right
J2: Conn_01x10_Socket; PinHeader_1x10_P2.54mm_Vertical_SMD_Pin1Left
J3: Conn_02x03_Counter_Clockwise; IDC-Header_2x03_P2.54mm_Vertical
J4, J5, J6, J7: Conn_01x01; SolderWirePad_1x01_SMD_1x2mm
J8: Conn_01x05_Socket; PinHeader_1x05_P2.54mm_Vertical_SMD_Pin1Left
J9: Conn_01x10_Socket; PinHeader_1x10_P2.54mm_Vertical_SMD_Pin1Right

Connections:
+3.3V: J2.1, J3.5, J9.1
/GP9: J1.1, J5.1, J8.1
/GP10: J2.8, J3.1, J9.8
/GP11: J2.7, J3.2, J9.7
/GP14: J2.6, J7.1, J9.6
/GP16: J1.2, J8.2
/GP17: J1.3, J8.3
/GP18: J1.4, J8.4
/GP19: J1.5, J4.1, J8.5
/GP28: J2.3, J6.1, J9.3
/SCL: J2.5, J3.4, J9.5
/SDA: J2.4, J3.3, J9.4
GND: J2.2, J2.9, J3.6, J9.2, J9.9
VCC: J2.10, J9.10

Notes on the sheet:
Double footprint to allow left and right 1st pinof SMD pin headers
SAO header
SAO header specs: https://hackaday.com/2019/03/20/introducing-the-shitty-add-on-v1-69bis-standard/
Pads for touch pads

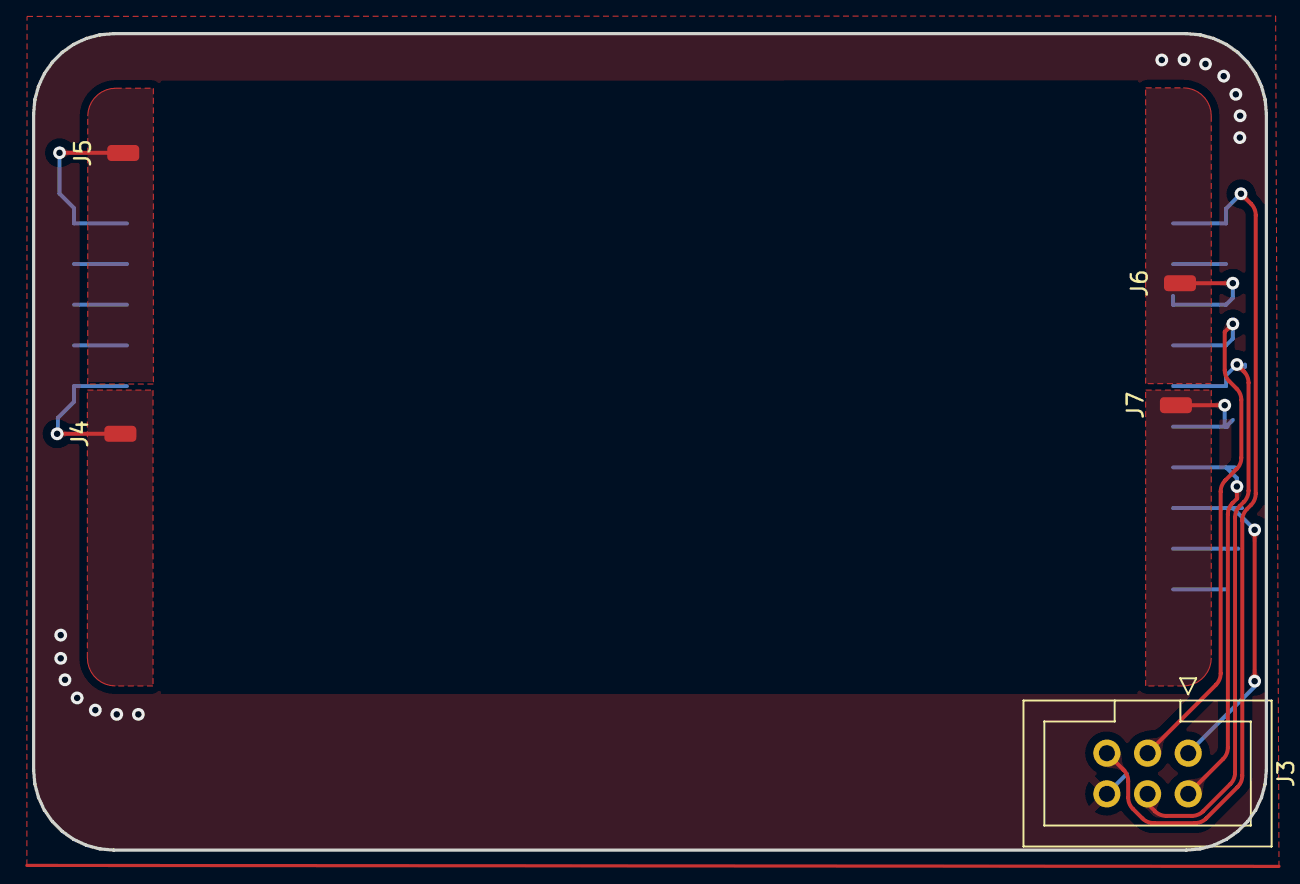
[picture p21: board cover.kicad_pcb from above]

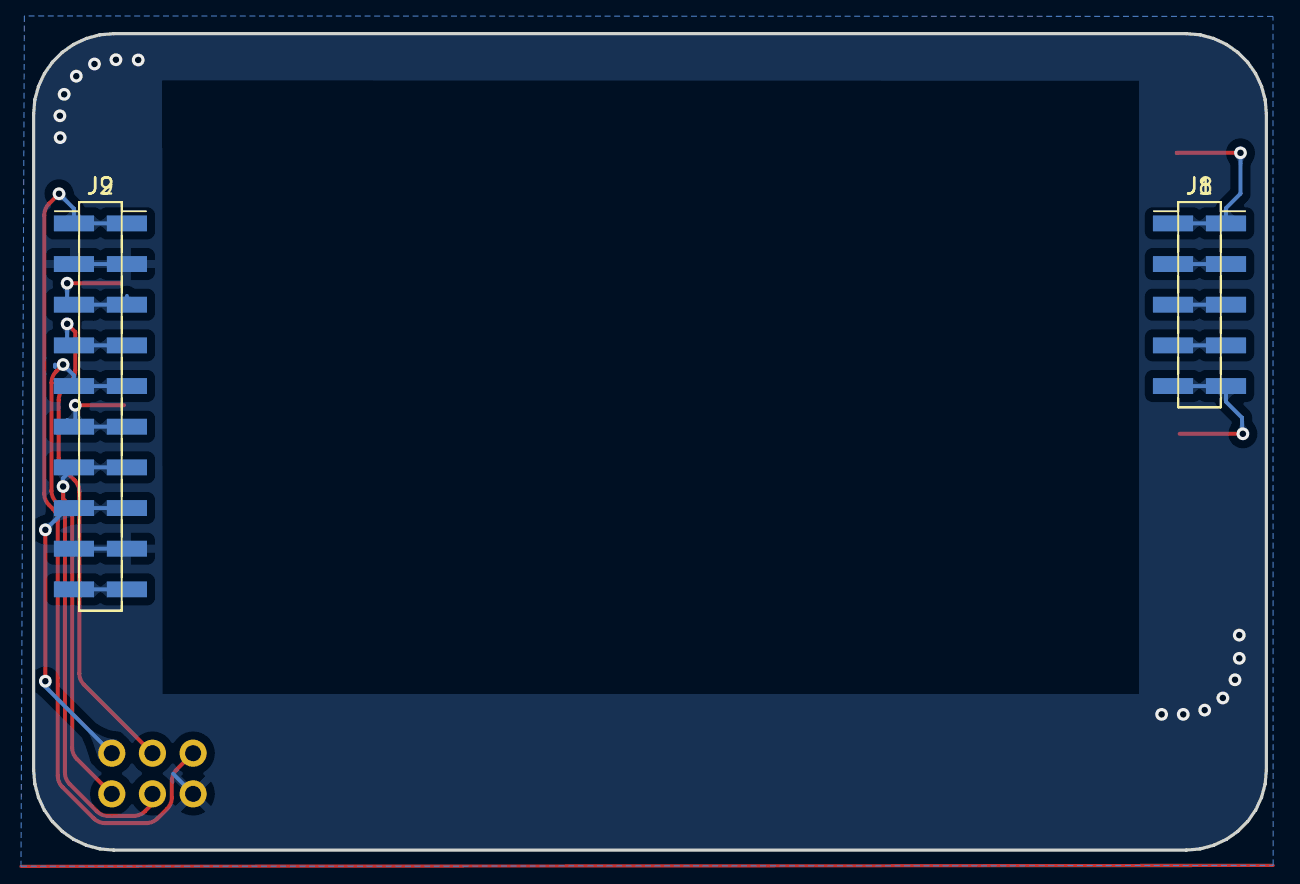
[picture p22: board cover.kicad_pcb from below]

Board: 2 copper layers, 77.0 x 51.0 mm, 9 parts (4 on the bottom side), 14 nets.

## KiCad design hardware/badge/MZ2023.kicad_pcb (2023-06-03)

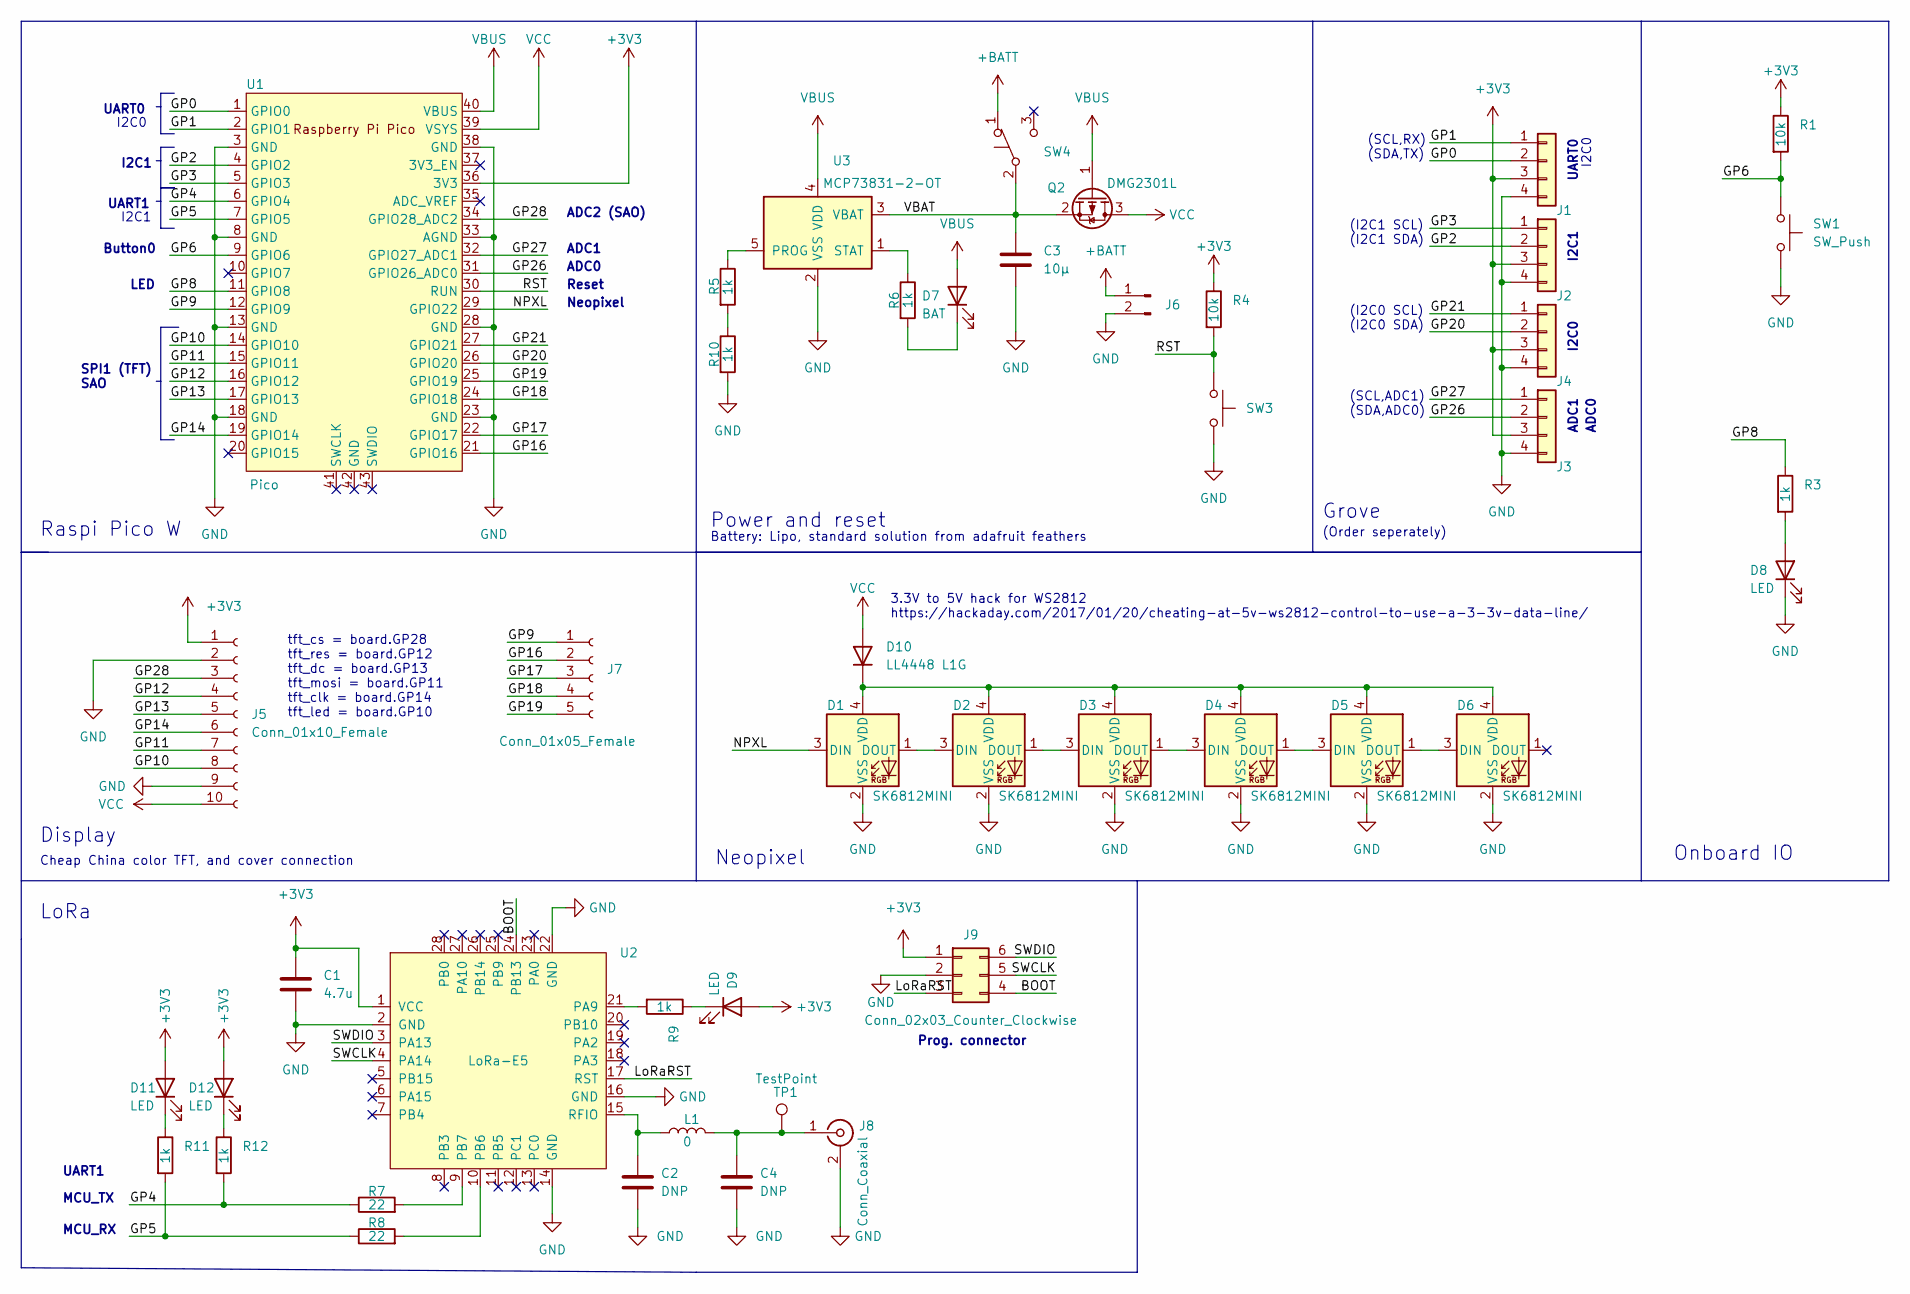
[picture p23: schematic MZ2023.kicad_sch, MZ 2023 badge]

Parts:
C1: 4.7u; C_0805_2012Metric; Mouser 187-CL21A475KPFNNNG
C2, C4: DNP; C_0603_1608Metric
C3: 10µ; C_1206_3216Metric_Pad1.33x1.80mm_HandSolder; Mouser 187-CL31A106MAHNNNE
D1, D2, D3, D4, D5, D6: SK6812MINI; LED_SK6812MINI_PLCC4_3.5x3.5mm_P1.75mm; Mouser 485-2659
D7: BAT; LED_0603_1608Metric_Pad1.05x0.95mm_HandSolder; Mouser 710-150060VS75000
D8, D9, D11, D12: LED; LED_0603_1608Metric_Pad1.05x0.95mm_HandSolder; Mouser 710-150060VS75000
D10: LL4448 L1G; D_MiniMELF; Digikey LL4448L1GCT-ND
J1, J2, J3, J4: Conn_01x04; Grove_SMD
J5: Conn_01x10_Female; PinHeader_1x10_P2.54mm_Vertical; Mouser 649-1012937891001BLF
J6: Conn_01x02_Male; JST_PH_S2B-PH-K_1x02_P2.00mm_Horizontal; Digikey 455-1719-ND
J7: Conn_01x05_Female; PinHeader_1x05_P2.54mm_Vertical; Mouser 649-1012937890503BLF
J8: Conn_Coaxial; U.FL_Hirose_U.FL-R-SMT-1_Vertical
J9: Conn_02x03_Counter_Clockwise; PinHeader_2x03_P2.54mm_Vertical_SMD
L1: 0; L_0805_2012Metric_Pad1.15x1.40mm_HandSolder; Mouser 603-RC0805FR-070RL
Q2: DMG2301L; SOT-23; Mouser 621-DMG2301L-7
R1, R4: 10k; R_0603_1608Metric; Mouser 603-RT0603FRE1310KL
R3, R5, R6, R9, R10, R11, R12: 1k; R_0603_1608Metric; Mouser 603-RT0603DRE071KL
R7, R8: 22; R_0603_1608Metric; Mouser 603-RT0603FRE0722RL
SW1, SW3: SW_Push; SW_Push_1P1T_NO_CK_KMR2; Digikey CKN10244CT-ND
SW4: SW_Push_SPDT; SW_CuK_OS102011MA1QN1_SPDT_Angled; Mouser 611-OS102011MA1QN1
TP1: TestPoint; PinHeader_1x01_P2.54mm_Vertical
U1: Pico; RPi_Pico_SMD_TH
U2: LoRa-E5
U3: MCP73831-2-OT; SOT-23-5; Mouser 579-MCP73831T-2ACIOT

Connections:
+3V3: C1.1, D9.2 (A), D11.2 (A), D12.2 (A), J1.3, J2.3, J3.3, J4.3, J5.1, J9.1, R1.1, R4.1, U1.36 (3V3), U2.1 (VCC)
+BATT: J6.1, SW4.1 (A)
/BOOT: J9.4, U2.24 (PB13~)
/GP0: J1.2, U1.1 (GPIO0)
/GP1: J1.1, U1.2 (GPIO1)
/GP2: J2.2, U1.4 (GPIO2)
/GP3: J2.1, U1.5 (GPIO3)
/GP4: R7.1, R12.2, U1.6 (GPIO4)
/GP5: R8.1, R11.2, U1.7 (GPIO5)
/GP6: R1.2, SW1.1, U1.9 (GPIO6)
/GP8: R3.1, U1.11 (GPIO8)
/GP9: J7.1, U1.12 (GPIO9)
/GP10: J5.8, U1.14 (GPIO10)
/GP11: J5.7, U1.15 (GPIO11)
/GP12: J5.4, U1.16 (GPIO12)
/GP13: J5.5, U1.17 (GPIO13)
/GP14: J5.6, U1.19 (GPIO14)
/GP16: J7.2, U1.21 (GPIO16)
/GP17: J7.3, U1.22 (GPIO17)
/GP18: J7.4, U1.24 (GPIO18)
/GP19: J7.5, U1.25 (GPIO19)
/GP20: J4.2, U1.26 (GPIO20)
/GP21: J4.1, U1.27 (GPIO21)
/GP26: J3.2, U1.31 (GPIO26_ADC0)
/GP27: J3.1, U1.32 (GPIO27_ADC1)
/GP28: J5.3, U1.34 (GPIO28_ADC2)
/LoRaRST: J9.3, U2.17 (RST)
/NPXL: D1.3 (DIN), U1.29 (GPIO22)
/RST: R4.2, SW3.1, U1.30 (RUN)
/SWCLK: J9.5, U2.4 (PA14)
/SWDIO: J9.6, U2.3 (PA13)
/VBAT: C3.1, Q2.2 (S), SW4.2 (B), U3.3 (VBAT)
GND: C1.2, C2.2, C3.2, C4.2, D1.2 (VSS), D2.2 (VSS), D3.2 (VSS), D4.2 (VSS), D5.2 (VSS), D6.2 (VSS), D8.1 (K), J1.4, J2.4, J3.4, J4.4, J5.2, J5.9, J6.2, J8.2 (Ext), J9.2, R10.2, SW1.2, SW3.2, U1.3 (GND), U1.8 (GND), U1.13 (GND), U1.18 (GND), U1.23 (GND), U1.28 (GND), U1.33 (AGND), U1.38 (GND), U2.2 (GND), U2.14 (GND), U2.16 (GND), U2.22 (GND), U3.2 (VSS)
unnamed: D1.1 (DOUT), D2.3 (DIN)
unnamed: D1.4 (VDD), D2.4 (VDD), D3.4 (VDD), D4.4 (VDD), D5.4 (VDD), D6.4 (VDD), D10.1 (K)
unnamed: D2.1 (DOUT), D3.3 (DIN)
unnamed: D3.1 (DOUT), D4.3 (DIN)
unnamed: D4.1 (DOUT), D5.3 (DIN)
unnamed: D5.1 (DOUT), D6.3 (DIN)
unnamed: D7.1 (K), R6.2
unnamed: D8.2 (A), R3.2
unnamed: D9.1 (K), R9.1
unnamed: D11.1 (K), R11.1
unnamed: D12.1 (K), R12.1
unnamed: C4.1, J8.1 (In), L1.2, TP1.1
unnamed: R5.2, R10.1
unnamed: R9.2, U2.21 (PA9)
unnamed: R8.2, U2.10 (PB6)
unnamed: R7.2, U2.9 (PB7)
unnamed: C2.1, L1.1, U2.15 (RFIO)
unnamed: R5.1, U3.5 (PROG)
unnamed: R6.1, U3.1 (STAT)
VBUS: D7.2 (A), Q2.1 (G), U1.40 (VBUS), U3.4 (VDD)
VCC: D10.2 (A), J5.10, Q2.3 (D), U1.39 (VSYS)

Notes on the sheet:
Power and reset
(I2C1 SCL) (I2C1 SDA)
Prog. connector
(SCL,RX) (SDA,TX)
I2C0
Cheap China color TFT, and cover connection
ADC1
Raspi Pico W
ADC2 (SAO)
ADC0
I2C1
Button0
(SCL,ADC1) (SDA,ADC0)
(Order seperately)
UART0
Reset
UART1
Neopixel
tft_cs = board.GP28 tft_res = board.GP12 tft_dc = board.GP13 tft_mosi = board.GP11 tft_clk = board.GP14 tft_led = board.GP10
(I2C0 SCL) (I2C0 SDA)
MCU_TX
3.3V to 5V hack for WS2812 https://hackaday.com/2017/01/20/cheating-at-5v-ws2812-control-to-use-a-3-3v-data-line/
MCU_RX
LoRa
Onboard IO
Display
Neopixel
Battery: Lipo, standard solution from adafruit feathers
LED
Grove
SPI1 (TFT) SAO

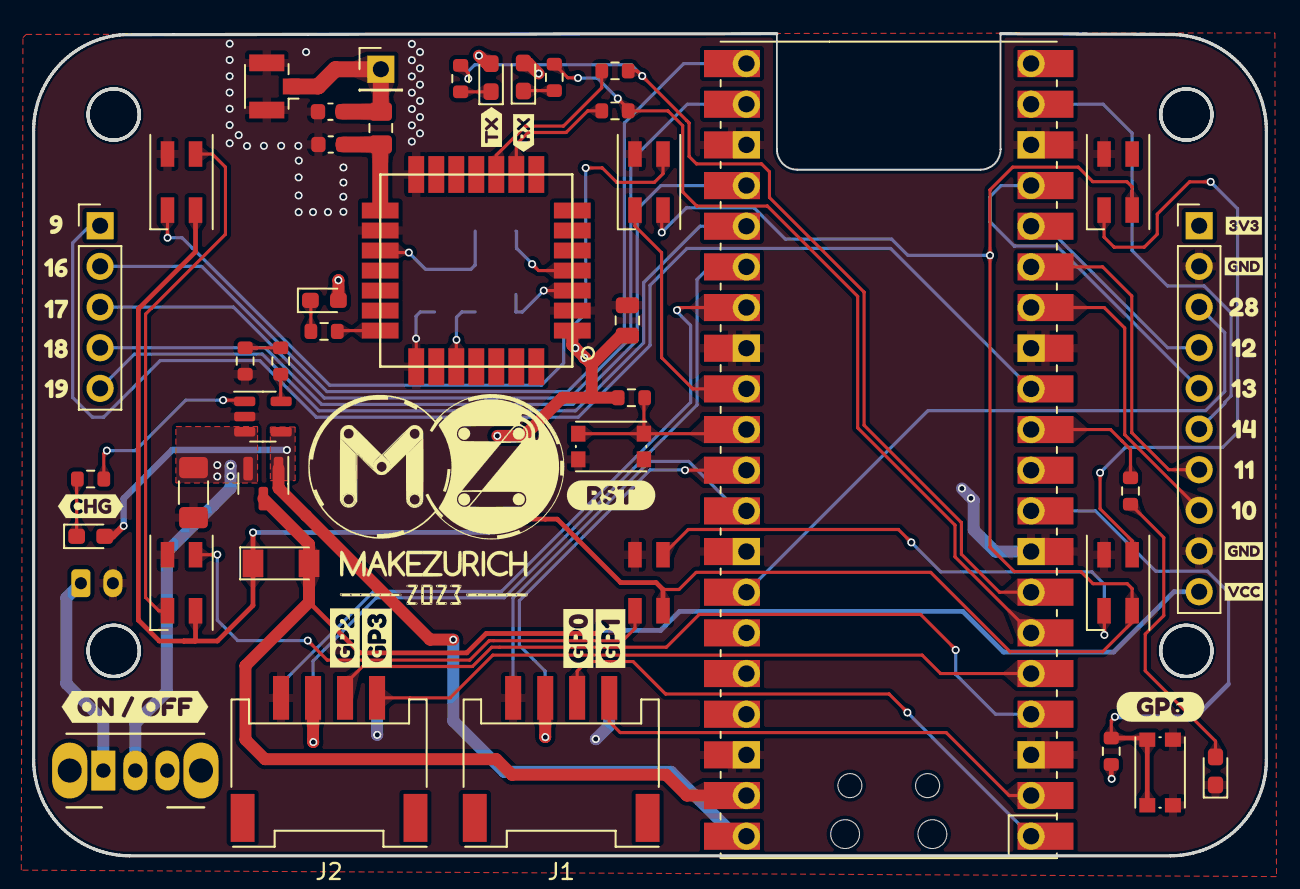
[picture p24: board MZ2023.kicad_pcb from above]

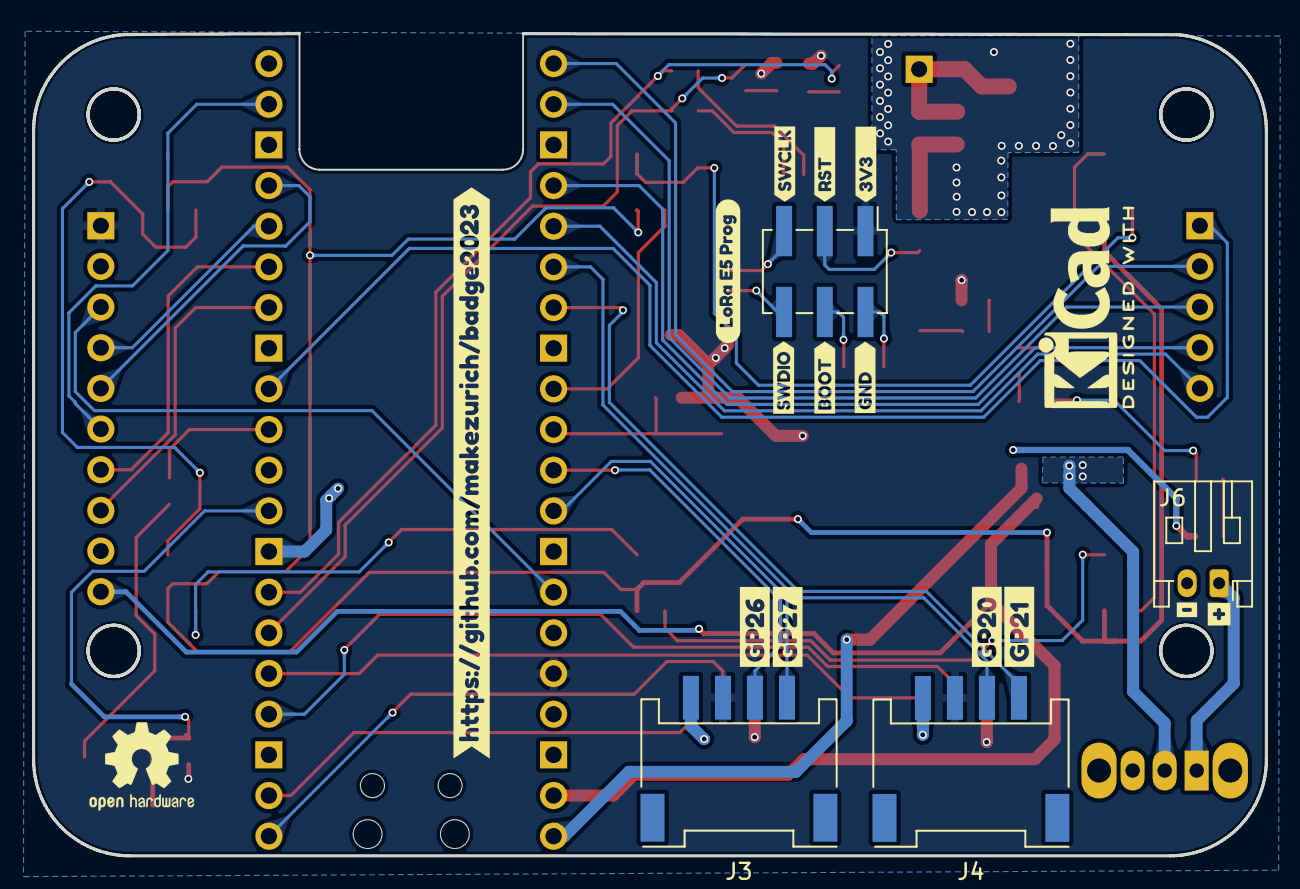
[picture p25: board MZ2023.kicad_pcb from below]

Board: 2 copper layers, 77.0 x 51.4 mm, 84 parts (18 on the bottom side), 54 nets.

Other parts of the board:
kibuzzard-637FABC0: G***; kibuzzard-637FABC0
kibuzzard-637FABEE: G***; kibuzzard-637FABEE
kibuzzard-637FABF7: G***; kibuzzard-637FABF7
kibuzzard-637FAC0A: G***; kibuzzard-637FAC0A
kibuzzard-637FAC01: G***; kibuzzard-637FAC01
kibuzzard-6368F4A2: G***; kibuzzard-6368F4A2
kibuzzard-6368F4DE: G***; kibuzzard-6368F4DE
kibuzzard-6368F4F7: G***; kibuzzard-6368F4F7
kibuzzard-6368F490: G***; kibuzzard-6368F490
kibuzzard-6368F495: G***; kibuzzard-6368F495
kibuzzard-6368F503: G***; kibuzzard-6368F503
kibuzzard-6368F610: G***; kibuzzard-6368F610
kibuzzard-6370DC90: G***; kibuzzard-6370DC90
kibuzzard-6370DC98: G***; kibuzzard-6370DC98
kibuzzard-6370DCA7: G***; kibuzzard-6370DCA7
kibuzzard-6372B00C: G***; kibuzzard-6372B00C
kibuzzard-6445C3D4: G***; kibuzzard-6445C3D4
kibuzzard-6445C3F3: G***; kibuzzard-6445C3F3
kibuzzard-6445C7AF: G***; kibuzzard-6445C7AF
kibuzzard-6445C7B7: G***; kibuzzard-6445C7B7
kibuzzard-6445C7DF: G***; kibuzzard-6445C7DF
kibuzzard-6445C7E9: G***; kibuzzard-6445C7E9
kibuzzard-6445C08E: G***; kibuzzard-6445C08E
kibuzzard-6445C19F: G***; kibuzzard-6445C19F
kibuzzard-6445C37B, kibuzzard-6445C37B#2: G***; kibuzzard-6445C37B
kibuzzard-6464F9A8: G***; kibuzzard-6464F9A8
kibuzzard-6464F92F: G***; kibuzzard-6464F92F
kibuzzard-6464F984: G***; kibuzzard-6464F984
kibuzzard-64568B8C: G***; kibuzzard-64568B8C
kibuzzard-64568C60: G***; kibuzzard-64568C60
kibuzzard-64568EFC: G***; kibuzzard-64568EFC
kibuzzard-64568F15: G***; kibuzzard-64568F15
kibuzzard-636923C0: G***; kibuzzard-636923C0
kibuzzard-6369234D: G***; kibuzzard-6369234D
kibuzzard-6461287C: G***; kibuzzard-6461287C
kibuzzard-63692365: G***; kibuzzard-63692365
kibuzzard-64457602: G***; kibuzzard-64457602
kibuzzard-64484314: G***; kibuzzard-64484314

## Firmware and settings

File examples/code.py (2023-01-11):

# print("Hello World")

# import time
# import board
# import pwmio
# import digitalio
# import analogio
# import busio
# import countio
# from adafruit_motor import servo
# import adafruit_mpr121

# from grove_i2c_relay import Relay
# import grove_ultrasonic_ranger

# # Servo on pin D22
# pwm = pwmio.PWMOut(board.D22, duty_cycle=2 ** 15, frequency=50)
# servo1 = servo.Servo(pwm)

# # Digital output on pin D13 (led)
# led = digitalio.DigitalInOut(board.D13)
# led.direction = digitalio.Direction.OUTPUT

# # Button on pin D2
# button1 = digitalio.DigitalInOut(board.D2)
# button1.direction = digitalio.Direction.INPUT
# button1.pull = digitalio.Pull.UP

# # Pir on pin D4 (edge counter)
# pir = countio.Counter(board.D4, edge=countio.Edge.RISE_AND_FALL)

# # Pot on pin A1
# pot1 = analogio.AnalogIn(board.A1)

# # Lightssensor on pin A0
# light_sensor = analogio.AnalogIn(board.A0)

# # Ultrasonic ranger on pin D3
# sonar = grove_ultrasonic_ranger.GroveUltrasonicRanger(sig_pin=board.D3)


# # MPR121 capsense on I2C
# i2c = busio.I2C(board.SCL, board.SDA)
# mpr121 = adafruit_mpr121.MPR121(i2c,address=91)

# # Relay on I2C
# relay = Relay(i2c,
#         device_address=0x11,
#         num_relays=4,
#         debug_action=True)


# def servo_test():
#     for angle in range(0, 180, 5):  # 0 - 180 degrees, 5 degrees at a time.
#         servo1.angle = angle
#         time.sleep(0.05)
#     for angle in range(180, 0, -5): # 180 - 0 degrees, 5 degrees at a time.
#         servo1.angle = angle
#         time.sleep(0.05)

# def relay_test(channels):
#     for i in range(channels):
#         relay.channel_on(i+1)
#         time.sleep(.5)
#         relay.channel_off(i+1)

# relay_test(4)


# while True:
#     if pir.count > 0:
#         relay.channel_on(1)
#     if pir.count > 1:
#         relay.channel_off(1)
#         pir.reset()

#     time.sleep(.1)


import board
import busio
import digitalio
import time
import supervisor
#Set UART Pin
uart = busio.UART(board.TX, board.RX, baudrate=9600)
get_input = True
message_started = False
message_print = []
allstring = ""
printshow = False
while True:
    if supervisor.runtime.serial_bytes_available:
        allstring=""
        userinput = input().strip() #input command
        b = bytes(userinput, 'utf-8')
        uart.write(b)
        continue
    byte_read = uart.readline()# read one line
    if byte_read != None:
        allstring += byte_read.decode()
        printshow = True
    else:
        if printshow == True:
            if allstring != "":
                print(allstring)
            allstring=""
            printshow ==False

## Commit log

2022-11-08 PCB Layout
    [MZ2023.kicad_pcb, MZ2023.kicad_sch]
2023-03-23 some parts anotated
    [MZ2023.kicad_pcb, MZ2023.kicad_sch]
2023-04-24 new version: * added Seeed Studio LoRa e5 module * changed WS2812 LED from 5x5mm to 3.5x3.5mm footprint * changed WS2812 LED positions. From circle to "rectangular" with intention of becoming the top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
    [MZ2023.kicad_pcb, MZ2023.kicad_sch]
2023-05-12 lora e5 v0.2 * changed grove connectors to right angle version * changed footprint for RDB LEDs WS2812B -> SK6812MINI (compatible with NeoPixels * mechanical switch (SW4) now cut the BAT+ instead of 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
    [MZ2023.kicad_pcb, MZ2023.kicad_sch]
2023-05-13 added GND under antenna, added teardrops
    [MZ2023.kicad_pcb]
2023-05-14 improvements to the LoRa antenna * changed the shape of the copper plane underneath the LoRa antenna path * moved D1-DOUT track on btm outside the antenna btm gnd plane
    [MZ2023.kicad_pcb]
2023-05-14 changing silk: lipo charge LED -> CHG
    [MZ2023.kicad_pcb]
2023-05-15 adding component Mouser/Digikey part numbers to schematic. Generating ibom
    [MZ2023.kicad_pcb, MZ2023.kicad_sch]
2023-05-15 parts numbers: completing digikey
    [MZ2023.kicad_sch]
2023-06-03 badge: improving bottomo slick
    [MZ2023.kicad_pcb]
2023-06-03 cover: adding nametag cover
    [cover.kicad_pcb, cover.kicad_sch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]
2023-06-03 badge: updating PDF layout
    [MZ2023.kicad_pcb]
2023-06-03 cover: adding PDFs schematic & layout
    [cover.kicad_pcb, cover.kicad_sch]
